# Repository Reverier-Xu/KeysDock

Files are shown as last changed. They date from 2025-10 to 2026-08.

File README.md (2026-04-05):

# Keys Dock

The hall-effect powered, high performance, feature riched keyboard!

> [!WARNING]
> **STILL IN EARLY DEVELOPMENT!**
>
> - [ ] PCB design
> - [ ] Suitkit design
> - [ ] Firmware
> - [ ] Software
> - [ ] Extended external controllers

## Keys layout

KeysDock uses main dock with 80-keys ANSI layout.

## Suitkit design

Designed use [FreeCAD](https://www.freecad.org/) for 3D modeling and [QCAD](https://www.qcad.org/) for nameplate drawn.

Fonts used in design:

- [Iosevka](https://typeof.net/Iosevka/): An elegant monospace coding font;
- [Hershey Fonts](https://en.wikipedia.org/wiki/Hershey_fonts): a collection of vector fonts originally designed to be rendered using vectors on early cathode ray tube displays.

## Hardware design

Designed use [KiCAD](https://www.kicad.org/), validated on [QUCS-s](https://ra3xdh.github.io/).

- MCU and BLE/WiFi: ESP32-C6
- ADC: TLA2518
- Hall-effect sensors: SC4823S6-TR
- Magnetic switch: Gateron Low Profile Magnetic Jade Pro Switch

More component info is available under [here](hardware/docs).

> [!WARNING]
> LIMITATIONS: the extended F-keys suite do not have sleep mode, awake functions and RGB lights.
> Hall-effect keyboard requires too many I/O pins, which makes difficulty in transfer additional features to external dock.

## Firmware

Rust 1.94 is required for build firmware.

## Software

WIP...

## Credits

This project is built entirely with opensource softwares, with power of opensource RISC-V instruction-set.

- [KiCAD](https://www.kicad.org): GPLv3
- [FreeCAD](https://www.freecad.org): LGPLv2.1
- [QCAD](https://www.qcad.org): GPLv3
- [Inkscape](https://www.inkscape.org): GPLv2
- [QUCS-s](https://ra3xdh.github.io): GPLv2
- [Rust](https://www.rust-lang.org): Apache-2.0 & MIT
- [esp-rs](https://docs.espressif.com/projects/rust/): Apache-2.0 & MIT

The current keyboard scheme can roughly be regarded as an original one.

Additionally, special thanks to [LCEDA](https://lceda.cn/), some 3D component models in this project are sourced from here.

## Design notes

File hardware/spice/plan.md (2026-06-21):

# KeysDock SPICE Simulation Plan

## Objective
Use ngspice to validate the KeysDock rev 0.3.0 hardware across power, analog, digital, and reliability domains.

## Model Sourcing Strategy
1. **First-party manufacturer models** — downloaded from TI where available and unencrypted.
2. **Third-party open-source libraries** — KiCad Spice Library, LTwiki, ngspice examples (checked; no direct matches for the exotic parts).
3. **Custom behavioral models** — built from datasheets when no compatible model exists.

## Model Inventory

| Component | MPN | Source | File | ngspice status | Usage |
|---|-----|---|---|---|---|
| Load switch | TPS22910AYZVR | TI first-party (SLVMA45A) | `models/vendor/ti/SLVMA45A/SLVMA45/TPS22910A_TRANS.LIB` | Reference only — uses PSpice digital primitives incompatible with ngspice 46 | Behavioral replacement used in sims |
| Buck converter | TPS62142RGTR | TI first-party (SLVM442B) | `models/vendor/ti/SLVM442B/TPS62142_PSPICE_TRANS/TPS62142_TRANS.lib` | Reference only — uses PSpice constructs incompatible with ngspice 46 | Behavioral replacement used in sims |
| ADC | TLA2528 (similar family) | TI first-party (SBAM431) | `models/vendor/ti/SBAM431/TLA2528_TRANS.LIB` | Reference only — TINA format, not ngspice compatible | Behavioral TLA2518 AFE used in sims |
| Charger / power-path | BQ24074RGTR | TI — **no SPICE model offered** | N/A | Custom behavioral | `models/custom/bq24074.lib` |
| Analog mux | XL4067TS | XINLUDA — no model | N/A | Custom behavioral | `models/custom/xl4067ts.lib` |
| Hall sensor | SC4823S6-TR | Semiment — no model | N/A | Custom behavioral | `models/custom/sc4823s6.lib` |
| RGB LED | XL-6028RGBW-WS2812B | XINGLIGHT — no model | N/A | Custom behavioral load | `models/custom/ws2812b.lib` |
| ESD array | TPD4E05U06DQAR | TI — no SPICE model | N/A | Generic TVS behavioral | `models/custom/tvs.lib` |
| ESD diode | TPD1E10B06DPYR | TI — no SPICE model | N/A | Generic TVS behavioral | `models/custom/tvs.lib` |
| TVS | TS24CA | SHOU HAN — no model | N/A | Generic TVS behavioral | `models/custom/tvs.lib` |
| Schottky | SM4007PL | MCC — generic model | N/A | Generic diode | ngspice built-in + `models/custom/diode.lib` |
| Inductor | 2.2µH | cjiang — no model | N/A | Ideal + DCR | `models/custom/passive.lib` |

## Simulation Matrix

| ID | Title | Circuit | Key Metrics | Priority |
|----|---|---|---|---|
| SP01 | VBAT monitor divider & ADC input range | `circuits/sp01_vbat_divider.cir` | AIN7 vs VBAT, overvoltage at VBAT=4.5V | P0 |
| SP02 | BQ24074 power-path & charger behavior | `circuits/sp02_charger.cir` | +4V vs VIN/VBAT, charge current, TS fault | P0 |
| SP03 | TPS62142 buck regulation & load transient | `circuits/sp03_buck.cir` | Vout regulation, ripple, inrush with 220µF | P0 |
| SP04 | Hall → mux → ADC signal chain | `circuits/sp04_hall_mux_adc.cir` | Settling time, scan time, noise | P0 |
| SP05 | Mux crosstalk | `circuits/sp05_mux_crosstalk.cir` | Coupling from active channel to quiet channel | P1 |
| SP06 | Ground noise / NetTie star ground | `circuits/sp06_ground_noise.cir` | GNDA bounce vs GNDD with LED switching | P1 |
| SP07 | PDN impedance | `circuits/sp07_pdn_impedance.cir` | |Z| of +3.3V vs frequency | P1 |
| SP08 | Hall sleep / wake timing | `circuits/sp08_sleep_wake.cir` | RANA latency, SAKI_MOVE pulse | P1 |
| SP09 | USB VBUS TVS clamp | `circuits/sp09_usb_vbus_tvs.cir` | Clamp voltage, peak current | P1 |
| SP10 | USB data-line ESD clamp | `circuits/sp10_usb_data_tvs.cir` | D+/D- clamp, loading capacitance | P1 |
| SP11 | ADC reference / sampling glitches | `circuits/sp11_adc_sampling.cir` | Acquisition error vs source impedance | P1 |
| SP12 | TPS22910A LED load-switch inrush & current budget | `circuits/sp12_led_load_switch.cir` | Inrush, VCC droop, max DC current | P1 |
| SP13 | VBAT ripple and Schottky behavior | `circuits/sp13_vbat_ripple.cir` | Schottky behavior, battery ripple | P2 |
| SP14 | ESP32 strapping / power-on (behavioral) | `circuits/sp14_strapping.cir` | Boot pin levels at power-up | P2 |
| SP15 | Buck inductor current ripple | `circuits/sp15_inductor_ripple.cir` | Inductor current, saturation margin | P2 |
| SP16 | BQ24074 TS bias compliance | `circuits/sp16_ts_bias.cir` | TS/VIN window vs bias network | P0/P1 |

## How to Run

```bash
cd /home/reverier/Code/Hardware/KeysDock/hardware/spice
python3 scripts/run_all.py
```

Results are written to `results/` as CSV/PNG-compatible raw files and summarized in `reports/simulation-summary.md`.

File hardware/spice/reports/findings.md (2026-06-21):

# KeysDock SPICE Simulation Findings

## SP01

- Variables: v(v-sweep), v(vin), v(aout), i(vbat)
- **Result:** At VBAT=4.50V, AIN7=2.250V (ratio=0.500, expected 0.500). OK for TLA2518 0-3.3V range.
- Data points: 16

## SP02

- Variables: time, v(vusb), v(vin), v(bat), v(xbat.n_int), v(xu4.vin_ok)...
- **Result:** USB present: SYS=4.38V, BAT=3.55V, CHG=0.00V (charging (CHG active-low)), PGOOD=0.00V. TS bias at 750.0mV is valid (valid window 0.30V-2.10V).
- Data points: 826

## SP03

- Variables: time, v(vin), v(vreg), v(vout), i(vbuck), i(vin)
- **Result:** Vout min=-0.000V, max=3.300V, final=3.295V (target 3.3V). ~220µF output capacitance causes prolonged soft-start but regulates.
- Data points: 70040

## SP04

- Variables: time, v(vdd), v(mag), v(sleep), v(xhall.sleep_int), v(xhall.gidd_int1)...
- **Result:** Hall output step tracked by mux/ADC. Final ADC code=1.650V vs hall=1.650V. Settling is within ~1µs for 200Ω Ron + 20pF load.
- Data points: 3044

## SP05

- Variables: time, v(vdd), v(s0), v(s1), v(eb), v(a0)...
- Data points: 508

## SP06

- Variables: time, v(gndd), v(gnda), v(ref), v(ain), i(lret)...
- Data points: 50027

## SP07

- Variables: frequency, v(vout), v(xc1.n3), v(xc2.n3), v(xc3.n3), v(xc4.n3)...
- Data points: 141

## SP08

- Variables: time, v(vdd), v(mag), v(sleep), v(xhall.sleep_int), v(xhall.gidd_int1)...
- Data points: 1529

## SP09

- Variables: time, v(vbus), v(esd), i(vesd)
- Data points: 524

## SP10

- Variables: time, v(src), v(dp), i(vesd)
- Data points: 426

## SP11

- Variables: time, v(vin), v(adc_in), v(xs1.samp_node), v(xs1.g1_int1), v(samp)...
- Data points: 3020

## SP12

- Variables: time, v(src), v(vin), v(xu6.en_int), v(on), v(xu6.vout_ctrl)...
- **Result:** Max input current=2.000A (limited by model), final VCC=2.081V. 82 RGBW LEDs at full white draw ~4.9A, exceeding TPS22910A 2A rating and USB 500mA limit. Firmware must enforce current budget.
- Data points: 50018

## SP13

- Variables: time, v(bat), v(sys), i(vbat)
- Data points: 508

## SP16

- Variables: v(v-sweep), v(vin), v(xu4.vin_ok), v(ts_good), v(xu4.gts_int1), v(xu4.ts_ok)...
- **Result:** At VIN=6.0V: 10kΩ TS-to-GND (datasheet NTC-disabled) V_TS=0.750V (OK, charging enabled); 22kΩ/47kΩ divider-to-VIN V_TS=5.21V (FAULT, exceeds VCOLD). Current schematic is correct per BQ24074 datasheet.
- Data points: 16

## Summary of Critical Findings

1. **BQ24074 TS bias is correct in current schematic.** R14=10kΩ from TS to GND matches the BQ24074 datasheet recommendation for NTC-disabled applications (TS voltage = ~0.75V, inside the 0.30V-2.10V valid window). The earlier ratio-based threshold model was wrong.
2. **LED current budget violation.** 82 WS2812B RGBW LEDs at full white draw ~4.9A, exceeding the TPS22910A 2A switch rating and the USB-C 500mA advertised limit. Firmware must limit brightness based on power source.
3. **+3.3V output capacitance is large (~220µF).** TPS62142 regulates but soft-start is prolonged; verify loop stability and inrush on hardware.
4. **VBAT divider is correct.** R8/R9=100kΩ gives AIN7 = VBAT/2, staying within TLA2518 0-3.3V range for VBAT up to 4.5V.

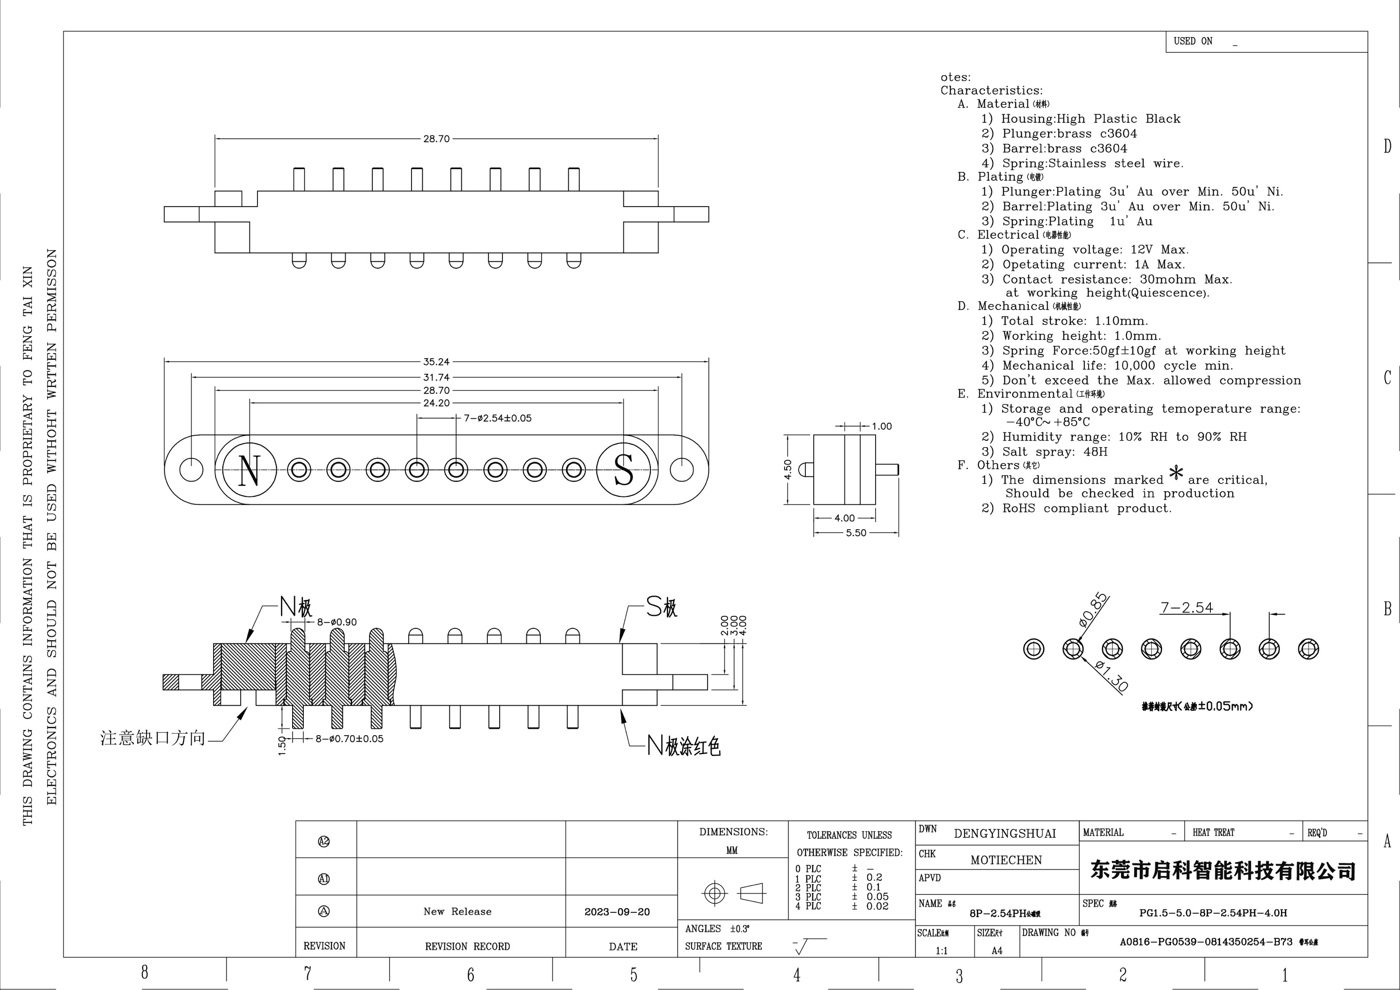
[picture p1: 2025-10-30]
hardware/docs/pogopin-ext.png

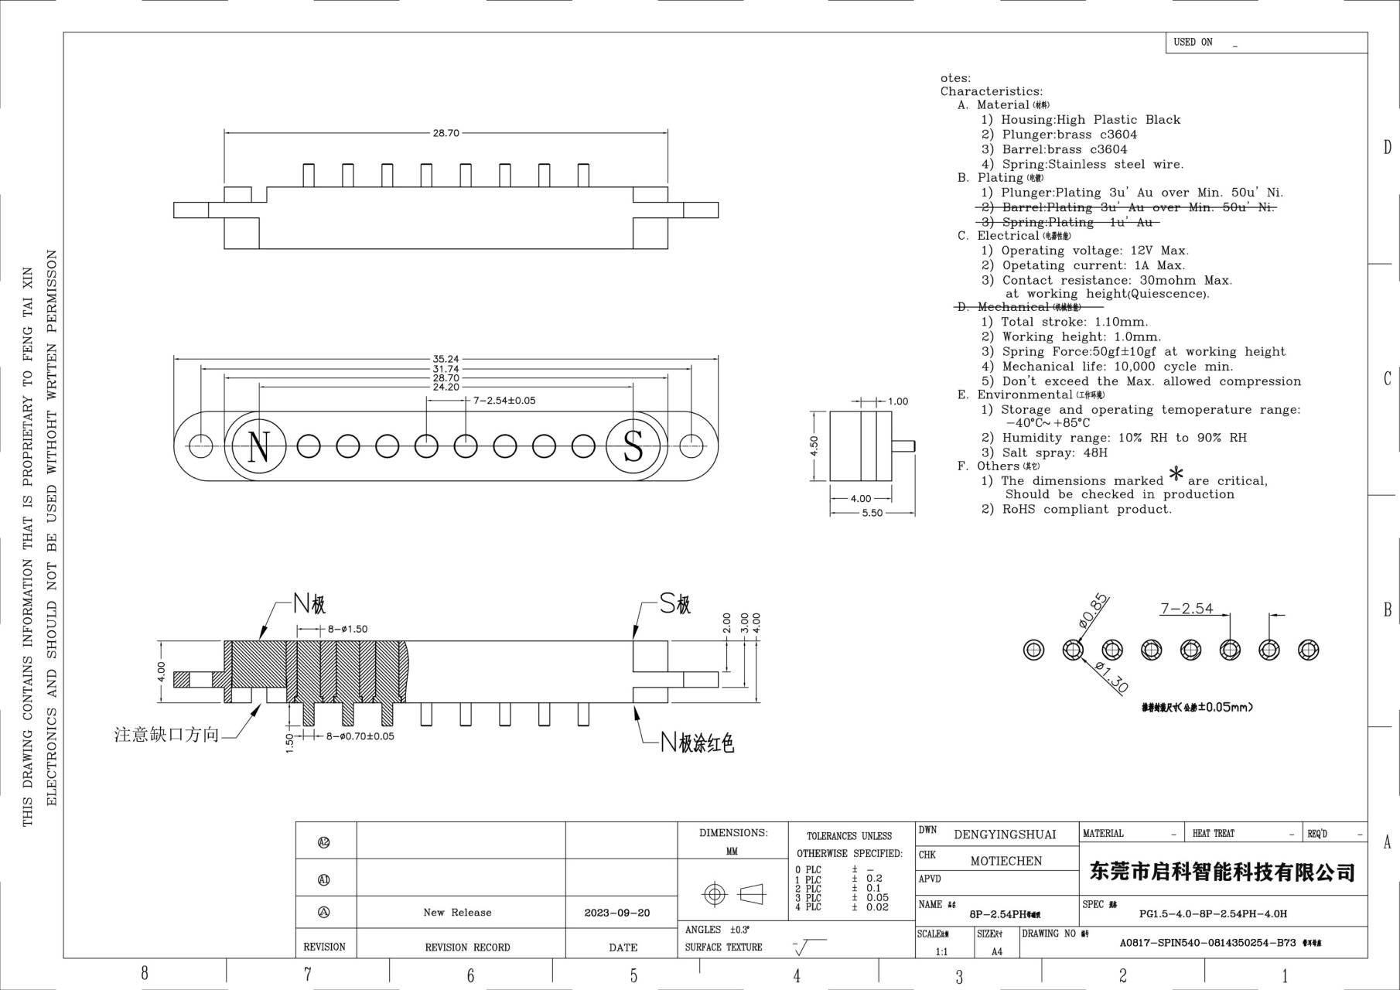
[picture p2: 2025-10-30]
hardware/docs/pogopin-main.png

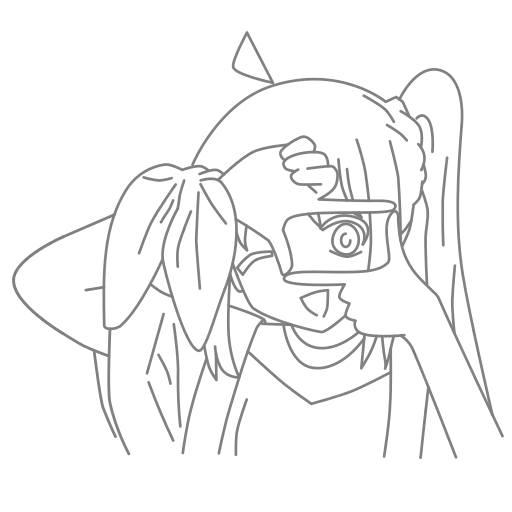
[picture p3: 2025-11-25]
arts/nijika.webp

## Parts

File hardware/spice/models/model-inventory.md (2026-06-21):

# SPICE Model Inventory

## First-party manufacturer models (reference)

| Part | Literature | Download URL | File location | Compatibility |
|---|---|---|---|---|
| TPS22910AYZVR | SLVMA45A | https://www.ti.com/lit/zip/SLVMA45A | `models/vendor/ti/SLVMA45A/` | PSpice; uses digital primitives that fail in ngspice 46 |
| TPS62142RGTR | SLVM442B | https://www.ti.com/lit/zip/SLVM442B | `models/vendor/ti/SLVM442B/` | PSpice unencrypted; uses constructs incompatible with ngspice 46 |
| TLA2528 (TLA2518 family) | SBAM431 | https://www.ti.com/lit/zip/SBAM431 | `models/vendor/ti/SBAM431/` | TINA format; not ngspice compatible |

## Third-party / open-source searches

- KiCad Spice Library (GitHub): no matches for XL4067TS, SC4823S6, BQ24074, TLA2518.
- LTwiki / ngspice examples: no specific models for these parts.
- Diodes Inc / ON Semi / Infineon libraries: not applicable to these TI/XINLUDA/Semiment parts.

## Custom behavioral models (used in simulations)

| Part | File | Basis |
|---|---|---|
| BQ24074RGTR | `models/custom/bq24074.lib` | Datasheet equations for charge current, input current limit, power-path, TS window |
| TPS62142RGTR | `models/custom/tps62142.lib` | Datasheet: fixed 3.3V, 2A current limit, soft-start, PG |
| TLA2518 AFE | `models/custom/tla2518_afe.lib` | Datasheet: 500Ω input switch, 12pF sample cap, 12-bit quantizer |
| TPS22910AYZVR | `models/custom/tps22910a.lib` | Datasheet: 60mΩ Ron, active-low, slew-limited turn-on, reverse-current protection |
| XL4067TS | `models/custom/xl4067ts.lib` | Datasheet: 200Ω Ron, 5pF channel cap, 20pF output cap |
| SC4823S6-TR | `models/custom/sc4823s6.lib` | Datasheet: 1.65V quiescent, 3.3mV/Gs, sleep/wake |
| WS2812B LED | `models/custom/ws2812b.lib` | Datasheet: 18-60mA per LED, 100nF decoupling |
| TVS diodes | `models/custom/diode.lib` | Datasheet clamp levels for TPD4E05U06, TPD1E10B06, TS24CA |
| Passives / traces | `models/custom/passive.lib` | Vendor typical ESL/ESR values for 0402/1206 caps and 2.2µH inductor |

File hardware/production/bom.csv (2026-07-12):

Designator | Footprint | Quantity | Value | LCSC Part #
C1, C12, C15, C2, C32, C4, C5 | C_0402 | 7 | 1uF | C52923
C10, C16, C19, C22, C25, C28, C31, C33, C34 | C_0402 | 9 | 10uF | C15525
C100, C101, C102, C103, C104, C105, C106, C107, C108, C109, C110, C111, C112, C113, C114, C115, C116, C117, C118, C17, C20, C23, C26, C29, C3, C37, C38, C39, C40, C41, C42, C43, C44, C45, C46, C47, C48, C49, C50, C51, C52, C53, C54, C55, C56, C57, C58, C59, C60, C61, C62, C63, C64, C65, C66, C67, C68, C69, C7, C70, C71, C72, C73, C74, C75, C76, C77, C78, C79, C8, C80, C81, C82, C83, C84, C85, C86, C87, C88, C89, C9, C90, C91, C92, C93, C94, C95, C96, C97, C98, C99 | C_0402 | 91 | 100nF | C1525
C11 | C_0402 | 1 | 3.3nF | C26404
C13, C14, C18, C21, C24, C27, C30 | C_0402 | 7 | 4.7uF | C23733
C35, C36 | C_1206 | 2 | 100uF | C15008
C6 | C_0402 | 1 | 22uF | C105226
D1 | D_SOD-123FL | 1 | SM4007PL | C78741
D2 | DIO_TPD1E05U06DPYR | 1 | TPD1E10B06DPYR | C48260
J1 | USB-C-SMD_SHOUHAN_TYPE-C-16PFS-2JCB1.2-H6.5 | 1 | TYPE-C 16PFS 2JCB1.2-H6.5 IPX8 | C3020046
L1 | IND-SMD_L2.5-W2.0_MHCHL2520 | 1 | 2.2uH | C5832372
LED1, LED10, LED11, LED12, LED13, LED14, LED15, LED16, LED17, LED18, LED19, LED2, LED20, LED21, LED22, LED23, LED24, LED25, LED26, LED27, LED28, LED29, LED3, LED30, LED31, LED32, LED33, LED34, LED35, LED36, LED37, LED38, LED39, LED4, LED40, LED41, LED42, LED43, LED44, LED45, LED46, LED47, LED48, LED49, LED5, LED50, LED51, LED52, LED53, LED54, LED55, LED56, LED57, LED58, LED59, LED6, LED60, LED61, LED62, LED63, LED64, LED65, LED66, LED67, LED68, LED69, LED7, LED70, LED71, LED72, LED73, LED74, LED75, LED76, LED77, LED78, LED79, LED8, LED80, LED81, LED82, LED9 | XL-6028RGBW-WS2812B | 82 | XL-6028RGBW-WS2812B | C42163197
PC1 | HC-1.25-4PWT | 1 | HC-1.25-4PWT | C2845381
PC2 | HC-1.25-2PWT | 1 | HC-1.25-2PWT | C2845379
R1, R11, R14, R2, R23, R3, R4 | R_0402 | 7 | 10kΩ | C25744
R10, R8, R9 | R_0402 | 3 | 100kΩ | C25741
R12, R13 | R_0402 | 2 | 1.5kΩ | C25867
R15 | R_0402 | 1 | 1.10kΩ | C25860
R16 | R_0402 | 1 | 47kΩ | C25792
R17 | R_0402 | 1 | 3kΩ | C25784
R18 | R_0402 | 1 | 750Ω | C25132
R19, R20 | R_0402 | 2 | 22Ω | C25092
R21, R22 | R_0402 | 2 | 5.1kΩ | C25941
R5, R6 | R_0402 | 2 | 100Ω | C25076
R7 | R_0402 | 1 | 499Ω | C4125
S1 | TS24CA | 1 | TS24CA | C393942
S2 | SW_TS-1088-AR02016 | 1 | TS-1088-AR02016, 160gf | C720477
S3 | SW-SMD_SSSS811101 | 1 | SSSS811101 | C109335
SW1, SW10, SW11, SW12, SW13, SW14, SW15, SW16, SW17, SW18, SW19, SW2, SW20, SW21, SW22, SW23, SW24, SW25, SW26, SW27, SW28, SW29, SW3, SW30, SW31, SW32, SW33, SW34, SW35, SW36, SW37, SW38, SW39, SW4, SW40, SW41, SW42, SW43, SW44, SW45, SW46, SW47, SW48, SW49, SW5, SW50, SW51, SW52, SW53, SW54, SW55, SW56, SW57, SW58, SW59, SW6, SW60, SW61, SW62, SW63, SW64, SW65, SW66, SW67, SW68, SW69, SW7, SW70, SW71, SW72, SW73, SW74, SW75, SW76, SW77, SW78, SW8, SW9 | KD-SINGLE-KEY | 78 | SC4823S6-TR | C52021064
T1, T2, T3, T4, T5 | XL4067TS | 5 | XL4067TS | C41427445
U1 | ESP32-C6-WROOM-1 | 1 | ESP32-C6-WROOM-1-N8
U2 | QFN50P300X300X80-17N | 1 | TLA2518IRTER | C1855741
U3 | QFN50P300X300X80-17N | 1 | TPS62142RGTR | C129331
U4 | QFN50P300X300X80-17N | 1 | BQ24074RGTR | C54313
U5 | IC_TPD4E05U06DQAR | 1 | TPD4E05U06DQAR | C138714
U6 | BGA4N50P2X2_88X88X50N | 1 | TPS22910AYZVR | C205966

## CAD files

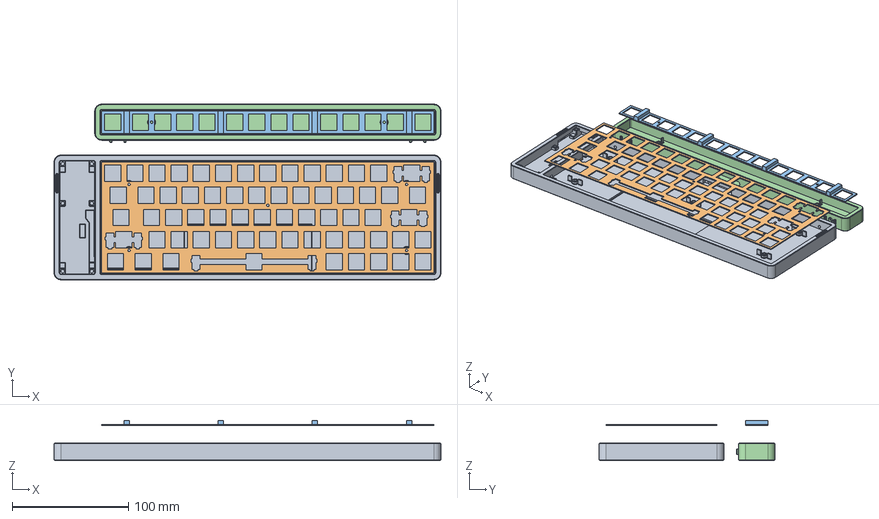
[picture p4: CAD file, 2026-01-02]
suitekits/full.FCStd
332.8 x 151.1 x 34.5 mm
Enclosure
Plate
FPlate
FEnclosure

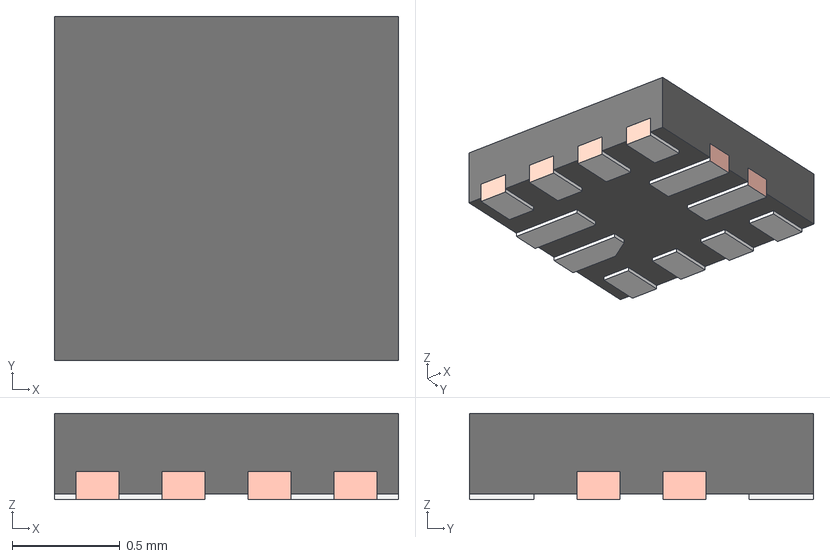
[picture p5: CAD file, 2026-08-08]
hardware/models/TUSB320LAIRWBR.step
1.60 x 1.60 x 0.4 mm
FRAME-RWB0012A
BODY-QFN

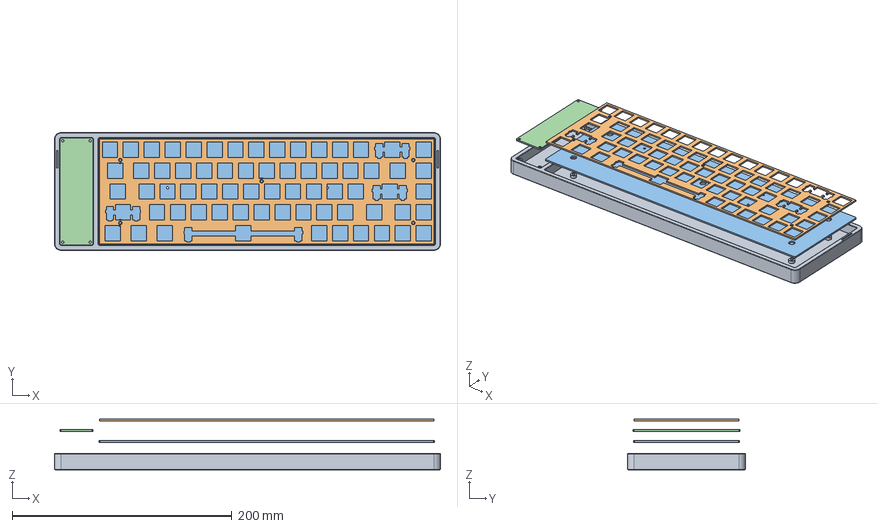
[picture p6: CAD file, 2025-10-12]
KeysDock65/suitekits/design.FCStd
351.5 x 107.2 x 46.1 mm
Enclosure
Plate
Stablizer
SideCover

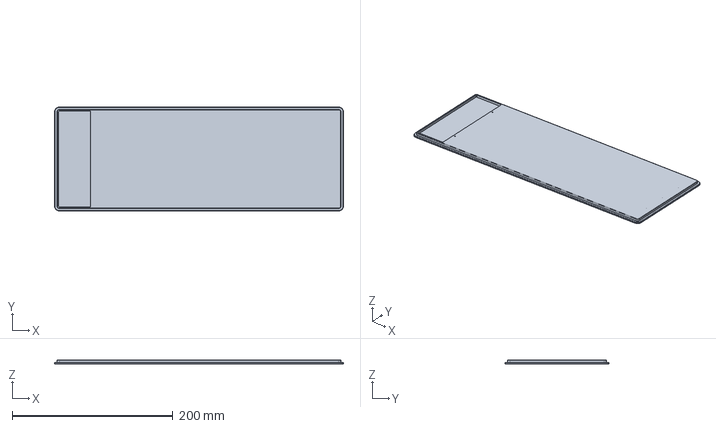
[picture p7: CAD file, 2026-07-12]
suitekits/KeysDock-Base.stp
359.8 x 129.3 x 5.00 mm

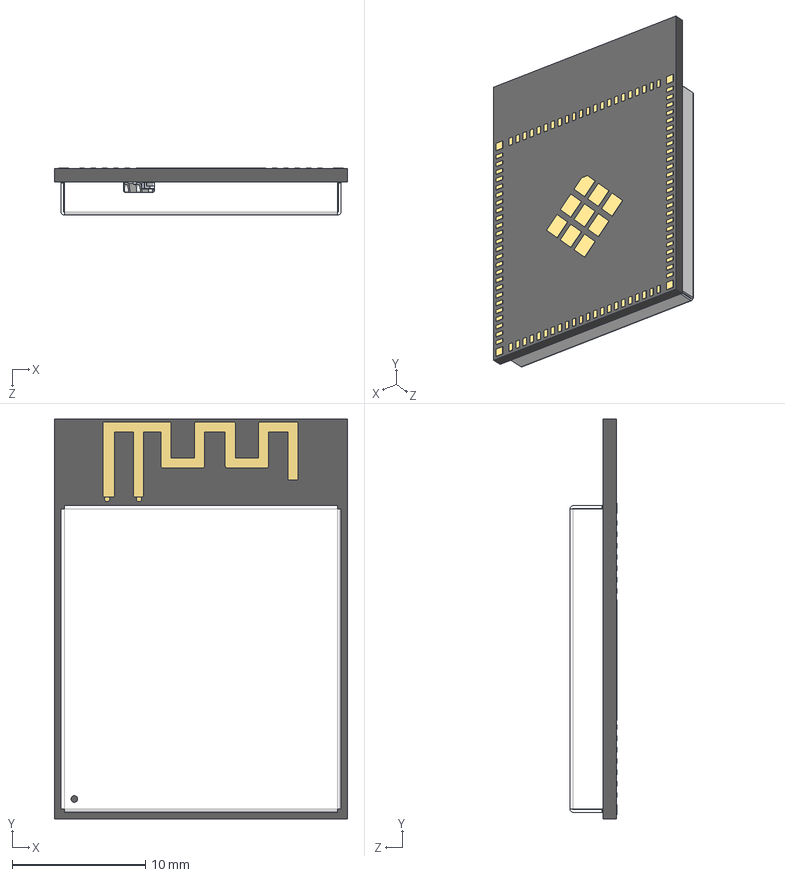
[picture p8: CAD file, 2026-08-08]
hardware/models/ESP32-S31-WROOM-3.step
22.0 x 30.0 x 3.54 mm
uid__4030
L0201_20210301.xtd x 5
C0201_20210301.xtd x 21
ESP32-S31 - 20260402.xtd
R0201_20210301.xtd x 11
SOD882.xtd
C0402_20210301.xtd x 3
SOP8_rev1_20210308.xtd
XTAL3225_20210301.xtd
Imported
MINI-ANT-TYPE-B
S31-wroom-3-solder_pad
ShieldBox_ESP32-S31-WROOM-3_V1.1_20260514

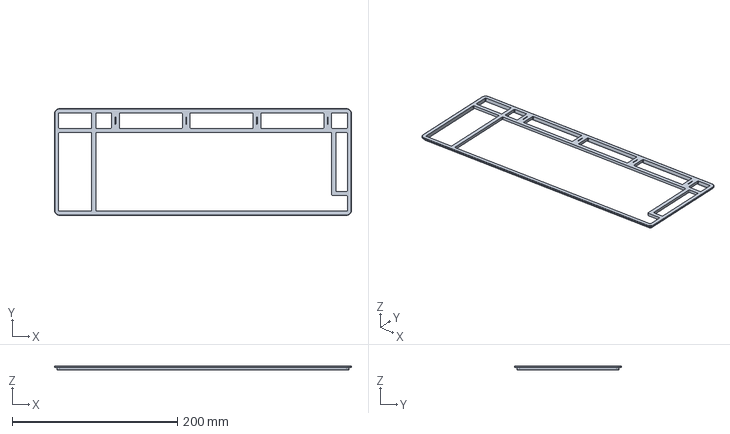
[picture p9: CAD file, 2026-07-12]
suitekits/KeysDock-Cover.stp
359.8 x 129.3 x 5.00 mm

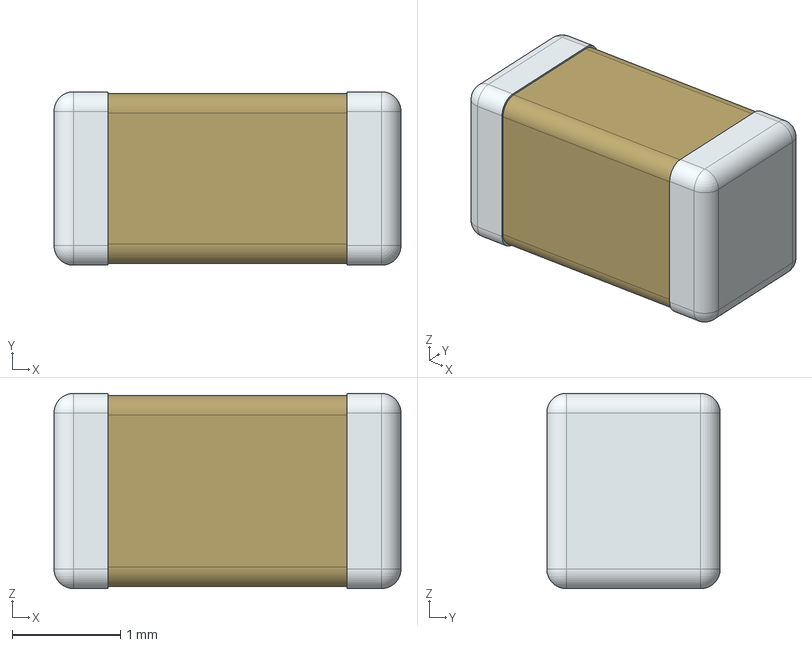
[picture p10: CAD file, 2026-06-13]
hardware/models/C_1206.step
3.20 x 1.60 x 1.80 mm

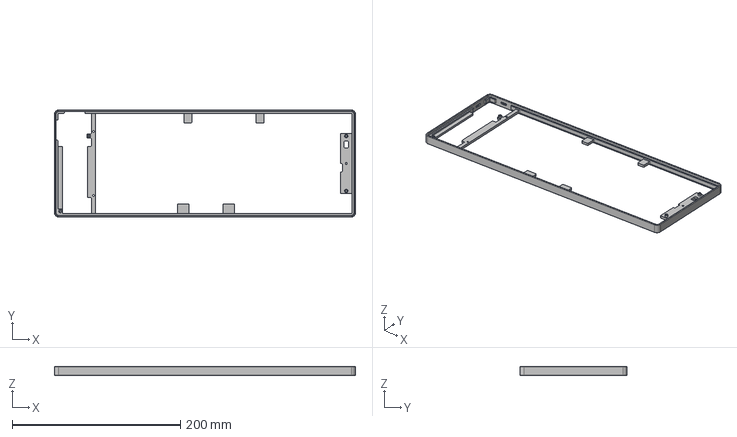
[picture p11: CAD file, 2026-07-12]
suitekits/KeysDock-Center.stp
357.8 x 127.3 x 11.0 mm

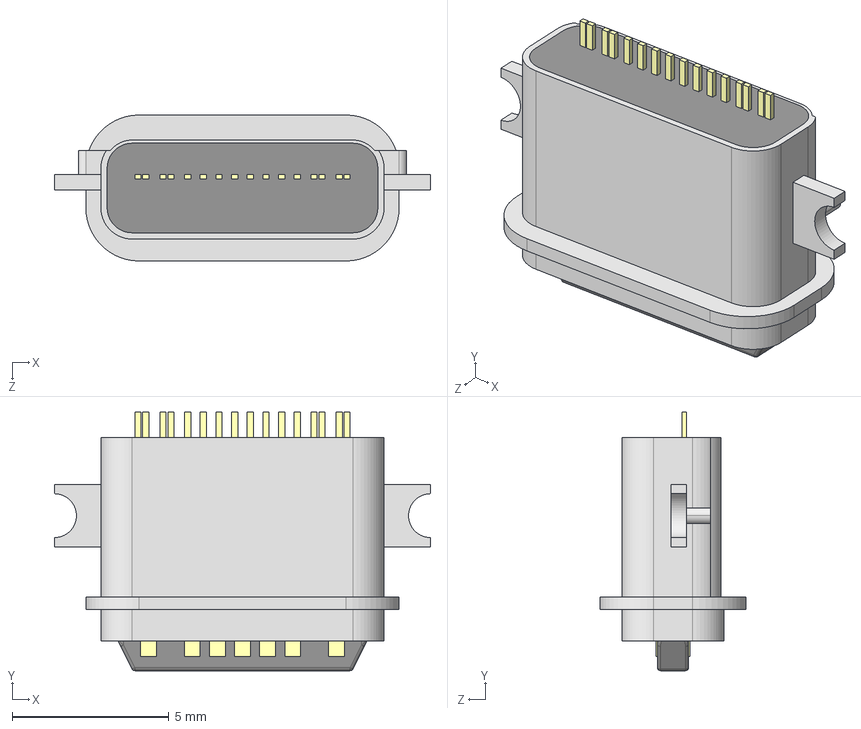
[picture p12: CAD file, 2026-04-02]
hardware/models/USB-C-SMD_SHOUHAN_TYPE-C-16PFS-2JCB1.2-H6.5.step
12.0 x 8.25 x 4.66 mm

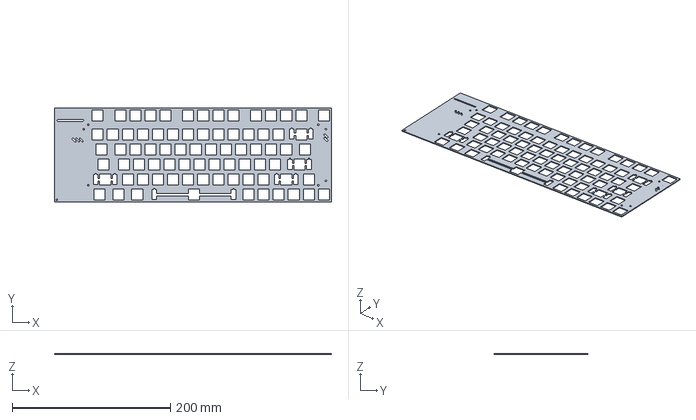
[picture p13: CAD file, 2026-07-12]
suitekits/KeysDock-Plate.stp
349.8 x 119.3 x 1.00 mm

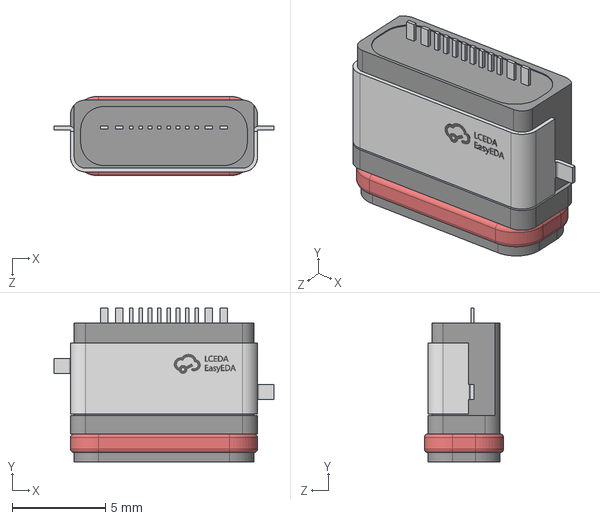
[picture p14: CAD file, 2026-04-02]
hardware/models/USB-C-SMD_SHOUHAN_TYPE-C-16PFS-2JCB1.2-H7.45.step
11.8 x 8.25 x 4.26 mm

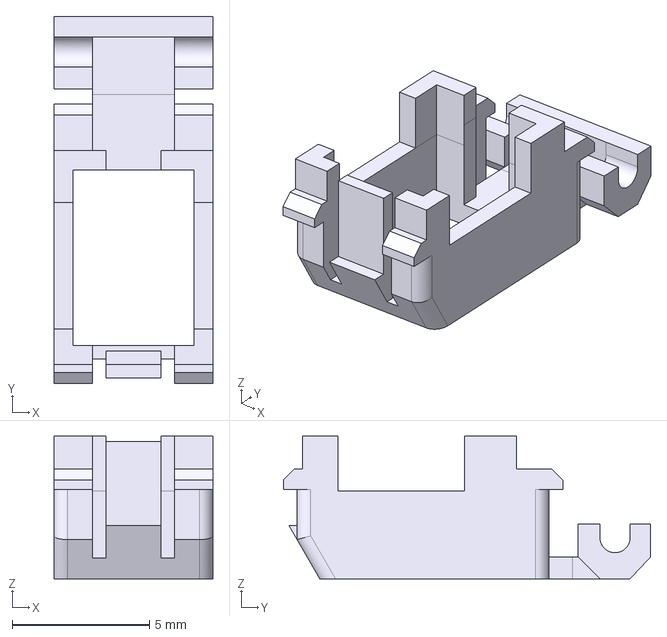
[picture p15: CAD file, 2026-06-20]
suitekits/KeysDock-Stabilizer-Mount.step
5.80 x 13.4 x 5.20 mm

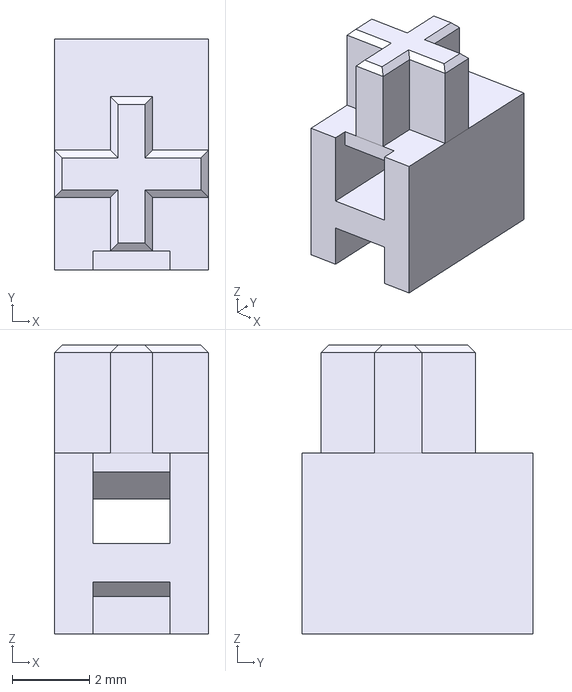
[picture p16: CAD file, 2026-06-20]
suitekits/KeysDock-Stabilizer-Route.step
4.00 x 6.00 x 7.50 mm

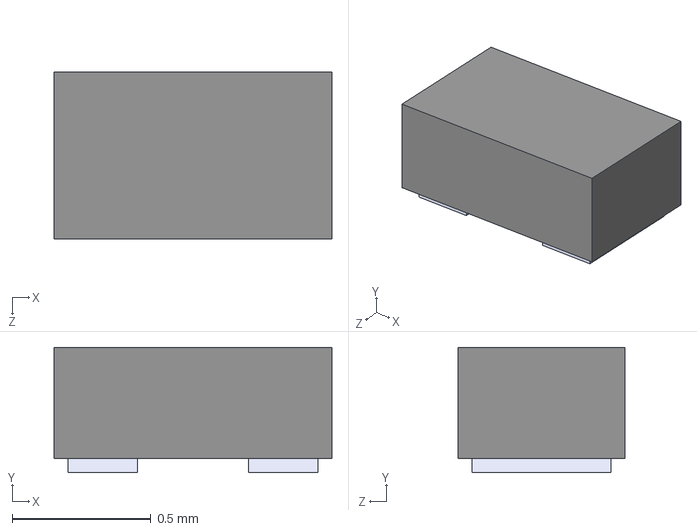
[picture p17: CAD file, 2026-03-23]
hardware/models/TPD1E10B06DPYR.step
1.00 x 0.45 x 0.6 mm

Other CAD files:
suitekits/KeysDock.FCStd
hardware/models/TPD4E05U06DQAR.step
hardware/models/LED-SMD_XL-3512RGBW.step
hardware/models/HC-TYPE-C-16P-CB1.6.step
hardware/models/AXK5F16347YG.step
hardware/models/AXK5F20347YG.step
hardware/models/AXK6F16347YG.step
hardware/models/AXK6F20347YG.step
hardware/models/BM28-16DP.stp
hardware/models/BM28-16DS.stp
hardware/models/CH334P.step
hardware/models/CH343P.step
hardware/models/C_0402.step
hardware/models/C_0603.step
hardware/models/Crystal_SMD-3225-4P.step
hardware/models/D_SOD-123FL.step
hardware/models/EC12E1240301.step
hardware/models/FPC-SMD_AFA01-S08FCA-00.step
hardware/models/FPC-SMD_AFC01-S12FCA-00.step
hardware/models/FPC-SMD_P0.50-16P_FGS-XJ-H2.0.step
hardware/models/HC-1.25-2PWT.step
hardware/models/HC-1.25-4PWT.step
hardware/models/IND-SMD_L2.5-W2.0_MHCHL2520.step
hardware/models/KS-33D-FB.step
hardware/models/LED-SMD_4P_XL-6028RGBW-WS2812B.step
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

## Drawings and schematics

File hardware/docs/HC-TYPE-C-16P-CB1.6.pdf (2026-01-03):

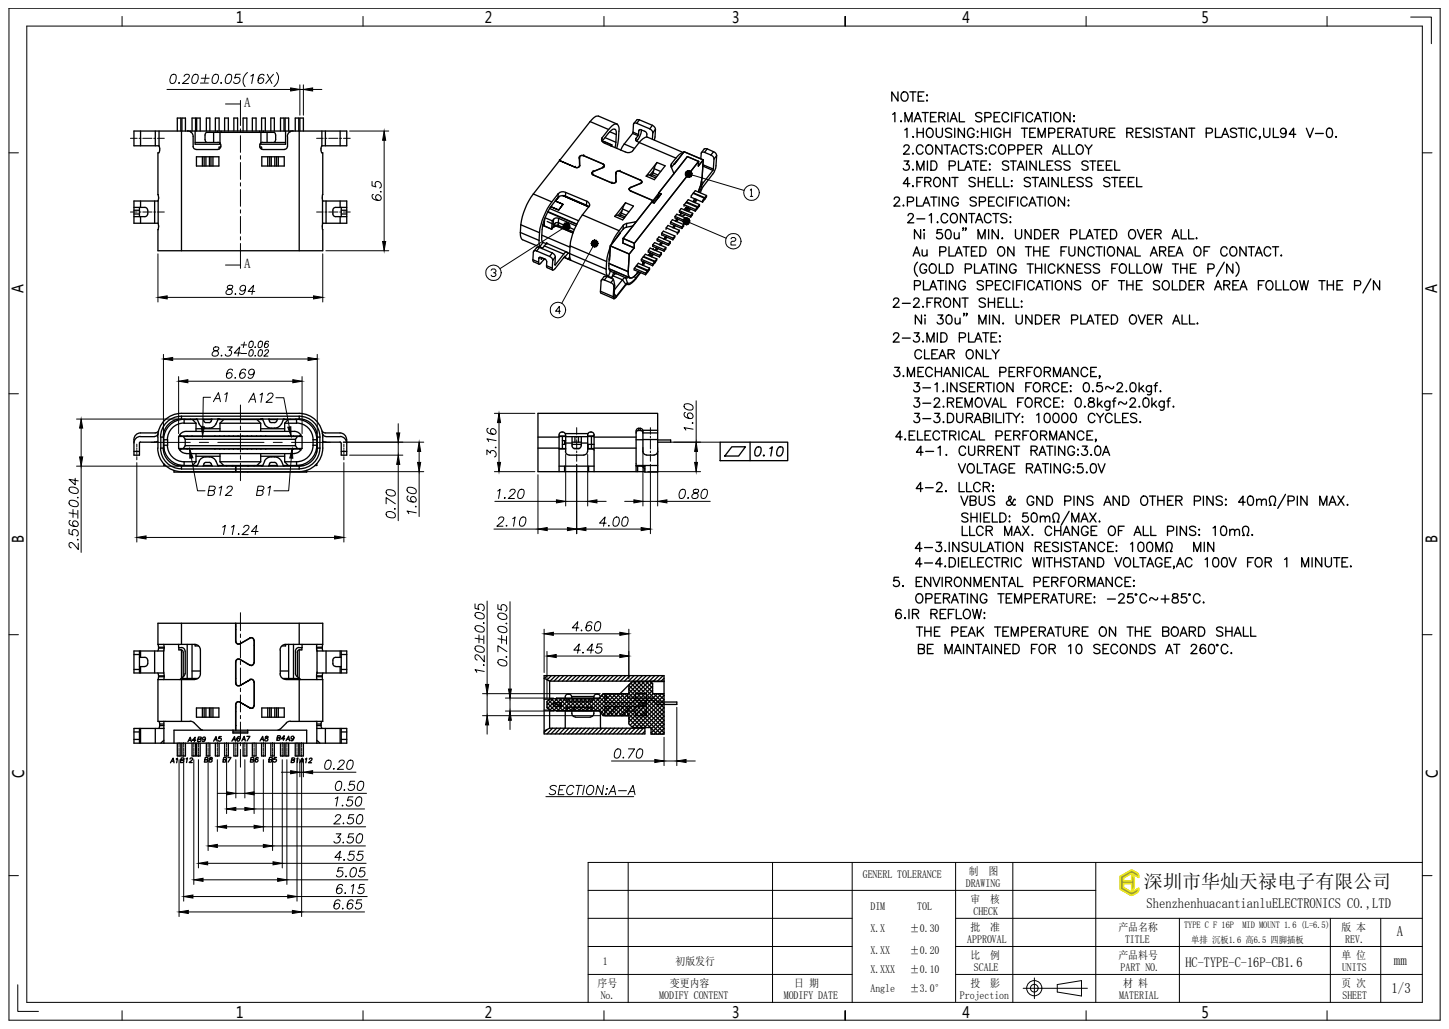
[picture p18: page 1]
HC-TYPE-C-16P-CB1.6 MATERIAL 材 料 PART NO. 产品料号 TITLE 产品名称 DRAWING 制 图 CHECK 审 核 APPROVAL 批 准 SCALE 比 例 Projection 投 影 GENERL TOLERANCE MODIFY DATE 日 期 MODIFY CONTENT 变更内容 1; 初版发行 No. 序号; REV. 版 本 UNITS 单 位 SHEET 页 次; mm 1/3 DIM; TOL X.X; ±0.20 X.XXX; ±0.10 Angle; 深圳市华灿天禄电子有限公司 ShenzhenhuacantianluELECTRONICS CO.,LTD A 1; B TYPE C F 16P MID MOUNT 1.6 (L=6.5) 单排 沉板1.6 高6.5 四脚插板 AA

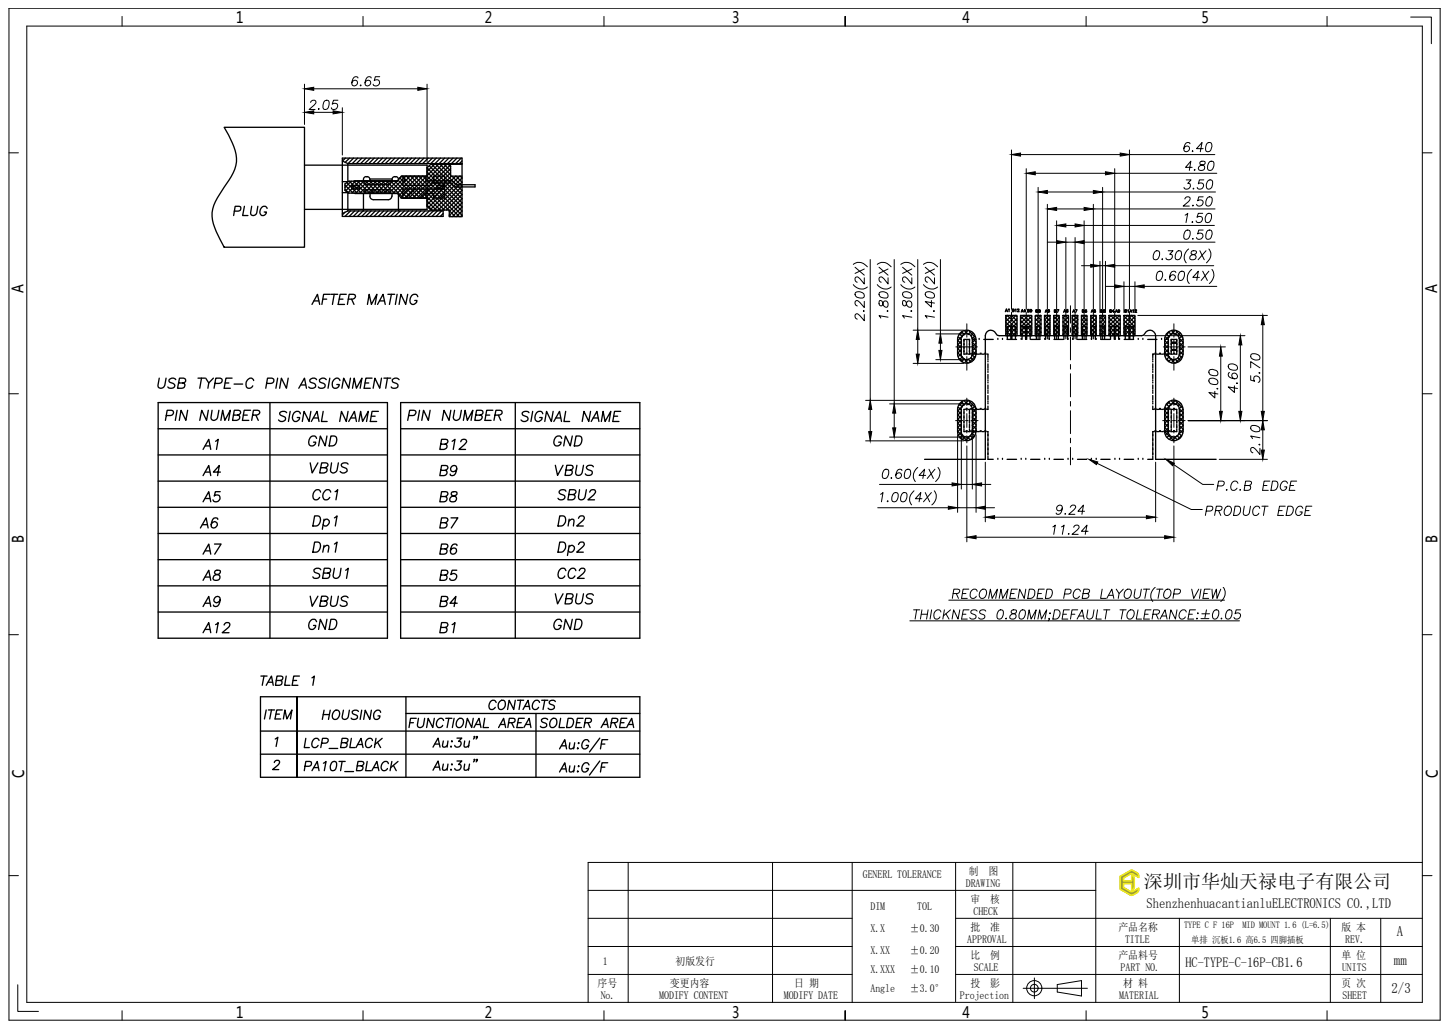
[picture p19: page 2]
HC-TYPE-C-16P-CB1.6 MATERIAL 材 料 PART NO. 产品料号 TITLE 产品名称 DRAWING 制 图 CHECK 审 核 APPROVAL 批 准 SCALE 比 例 Projection 投 影 GENERL TOLERANCE MODIFY DATE 日 期 MODIFY CONTENT 变更内容 1; 初版发行 No. 序号; REV. 版 本 UNITS 单 位 SHEET 页 次; mm 2/3 DIM; TOL X.X; ±0.20 X.XXX; ±0.10 Angle; 深圳市华灿天禄电子有限公司 ShenzhenhuacantianluELECTRONICS CO.,LTD A 1; B TYPE C F 16P MID MOUNT 1.6 (L=6.5) 单排 沉板1.6 高6.5 四脚插板

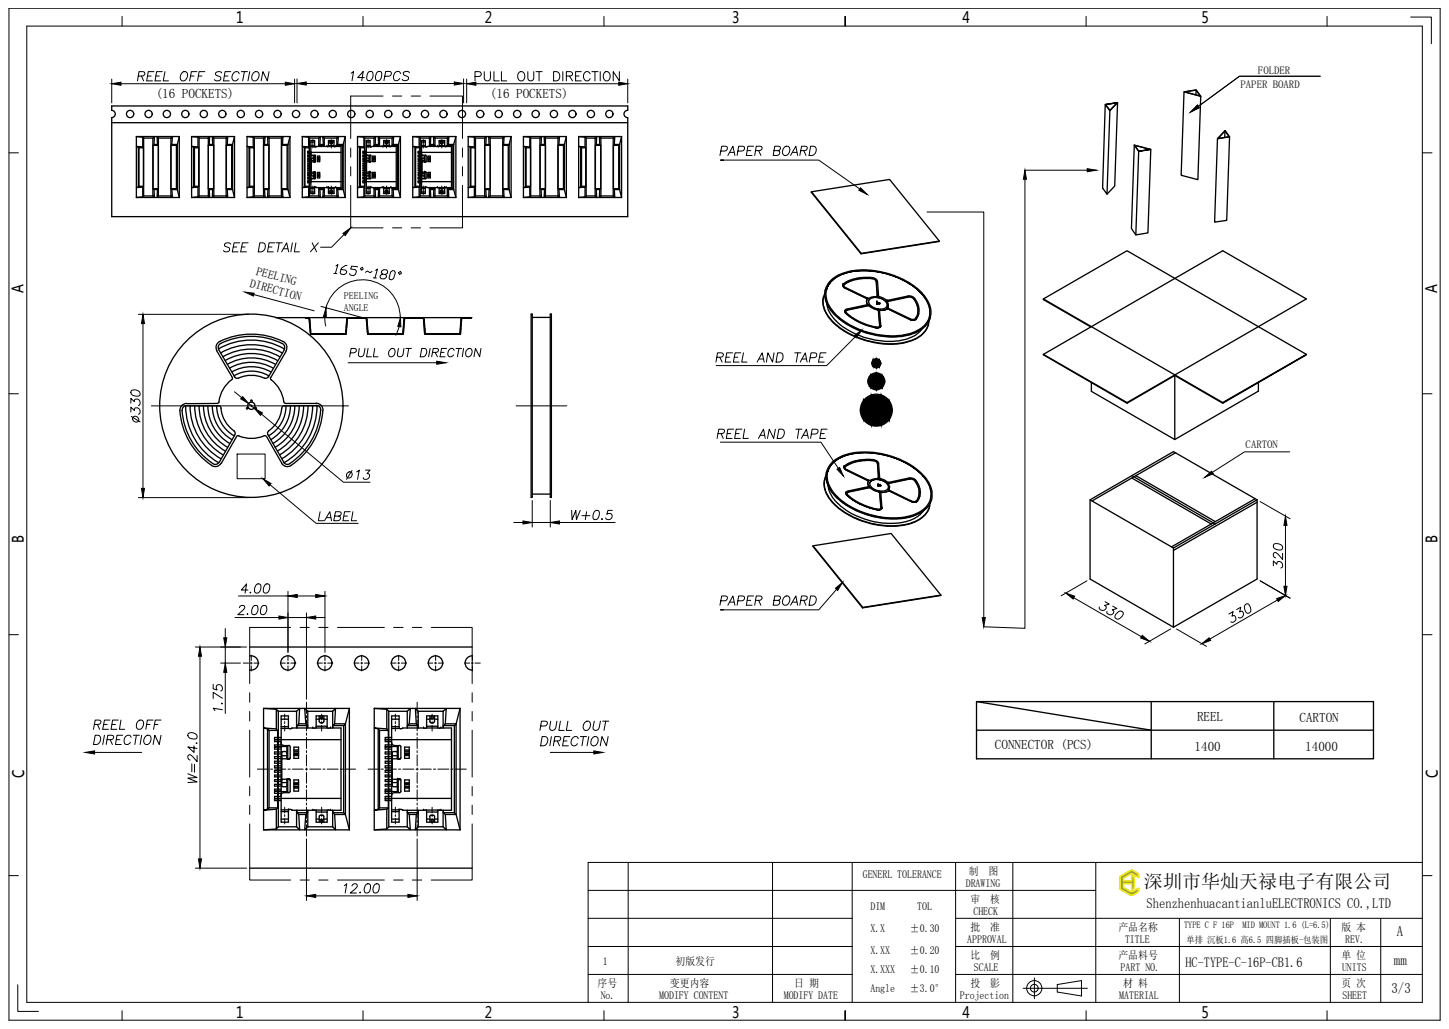
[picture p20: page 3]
HC-TYPE-C-16P-CB1.6 MATERIAL 材 料 PART NO. 产品料号 TITLE 产品名称 DRAWING 制 图 CHECK 审 核 APPROVAL 批 准 SCALE 比 例 Projection 投 影 GENERL TOLERANCE MODIFY DATE 日 期 MODIFY CONTENT 变更内容 1; 初版发行 No. 序号; REV. 版 本 UNITS 单 位 SHEET 页 次; mm 3/3 DIM; TOL X.X; ±0.20 X.XXX; ±0.10 Angle; 深圳市华灿天禄电子有限公司 ShenzhenhuacantianluELECTRONICS CO.,LTD A 1; B TYPE C F 16P MID MOUNT 1.6 (L=6.5) 单排 沉板1.6 高6.5 四脚插板-包装图 PEELING DIRECTION (16 POCKETS); (16 POCKETS) PEELING ANGLE; CONNECTOR (PCS); 14000 REEL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

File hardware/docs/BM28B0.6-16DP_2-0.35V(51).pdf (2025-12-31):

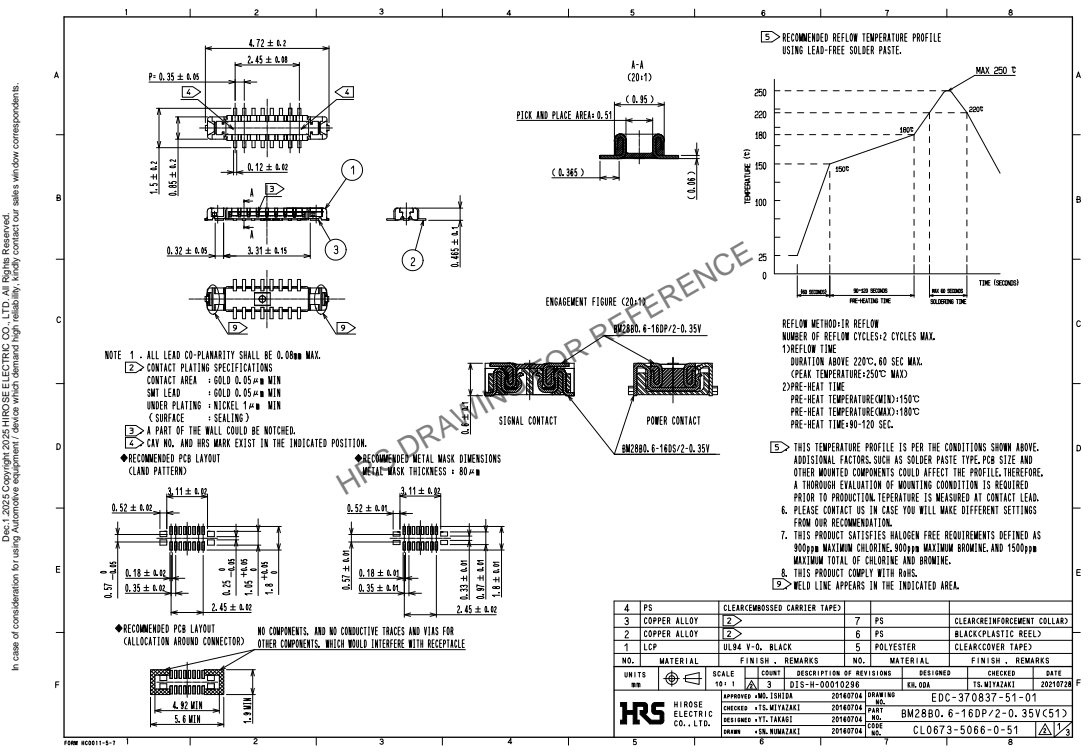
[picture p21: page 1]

HRS DRAWING FOR REFERENCE

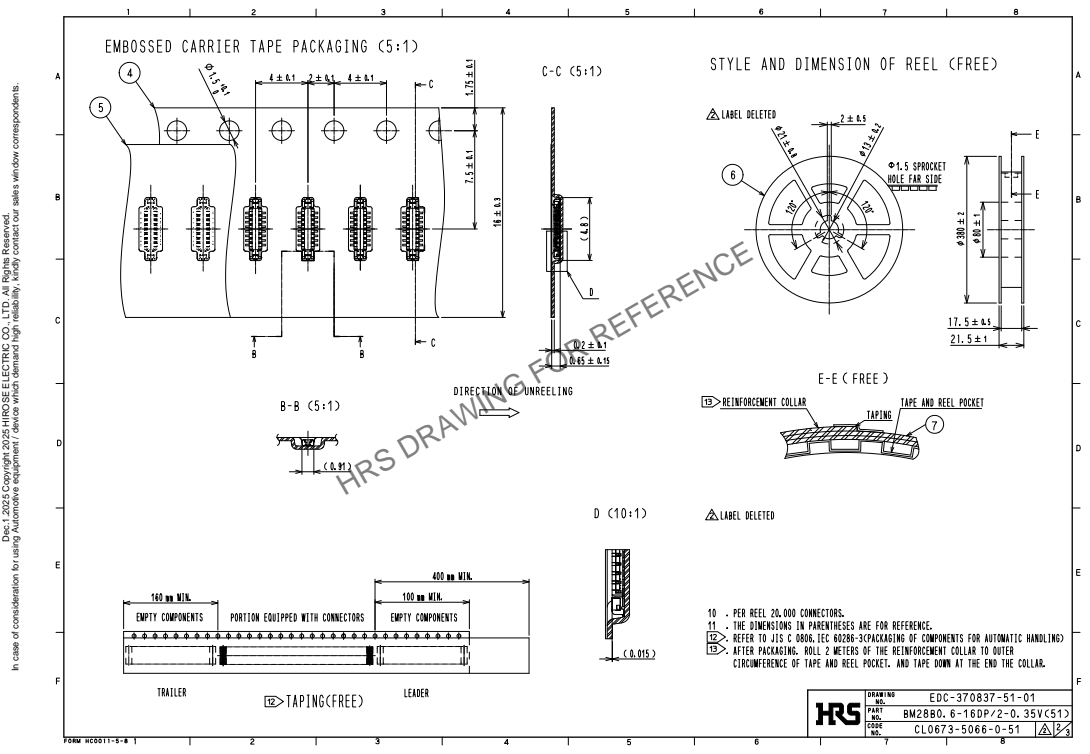
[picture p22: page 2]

HRS DRAWING FOR REFERENCE

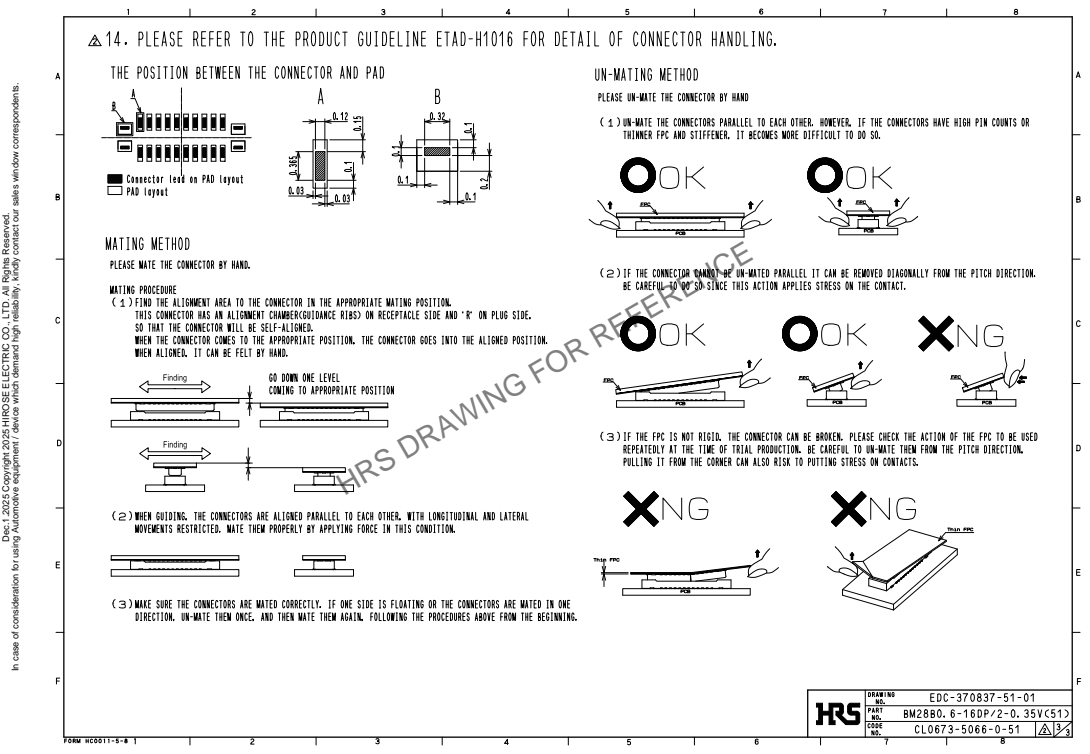
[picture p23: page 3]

HRS DRAWING FOR REFERENCE

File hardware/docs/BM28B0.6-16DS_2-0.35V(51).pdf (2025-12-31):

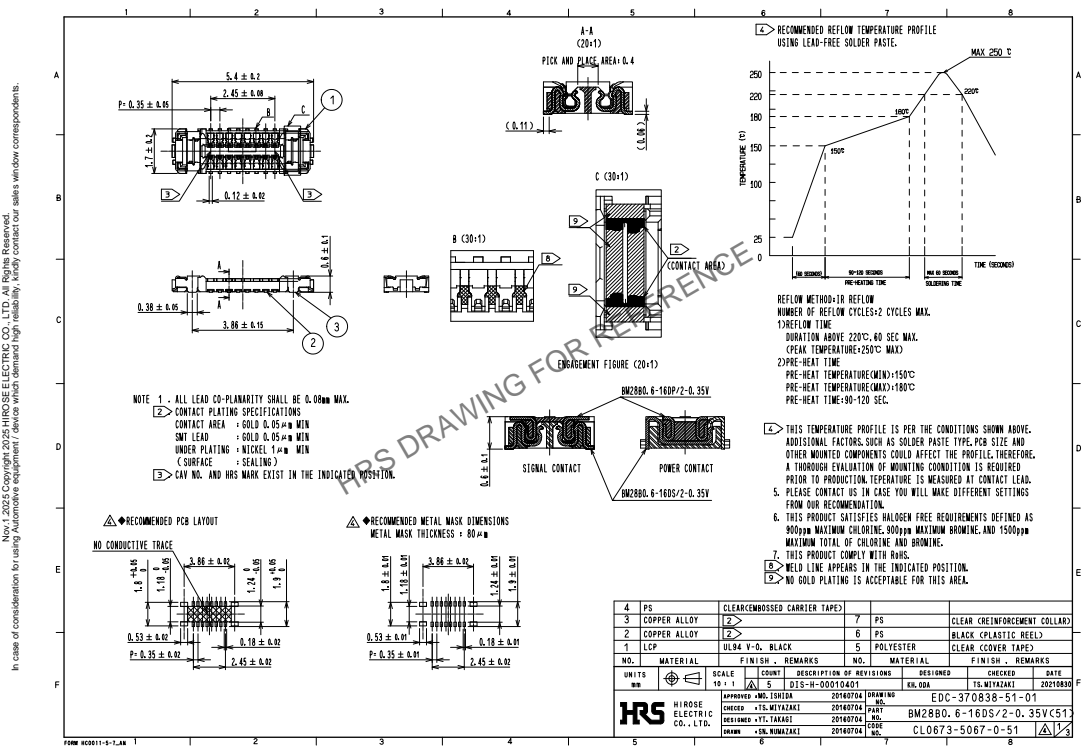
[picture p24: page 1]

HRS DRAWING FOR REFERENCE

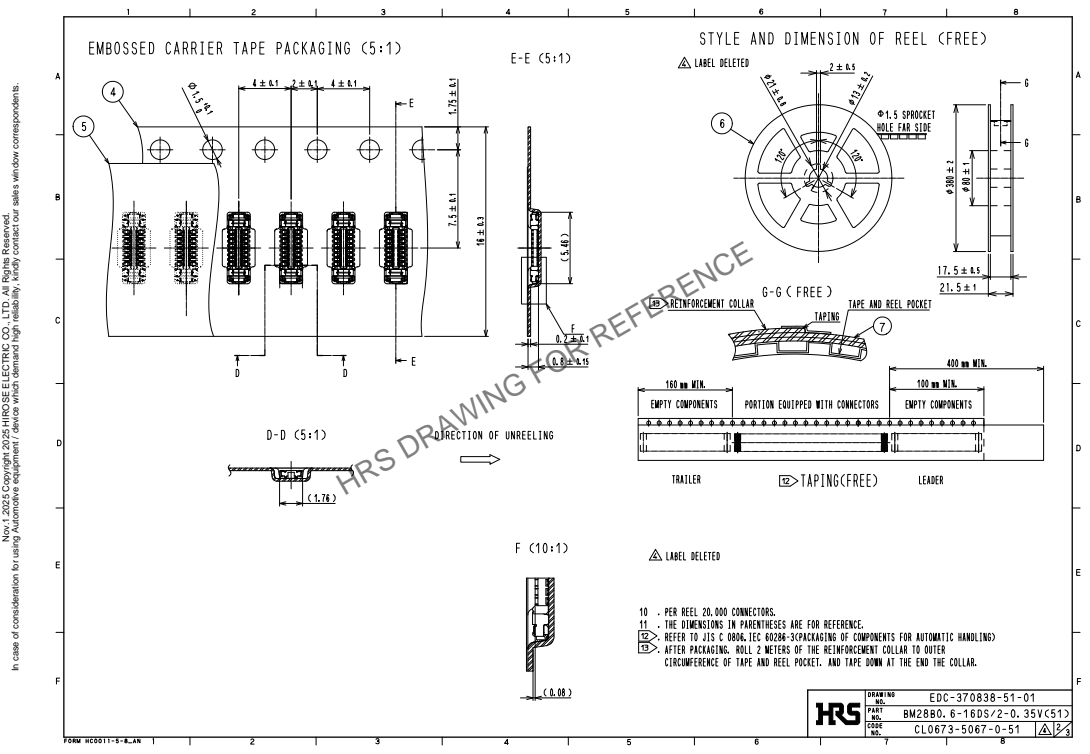
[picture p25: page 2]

HRS DRAWING FOR REFERENCE

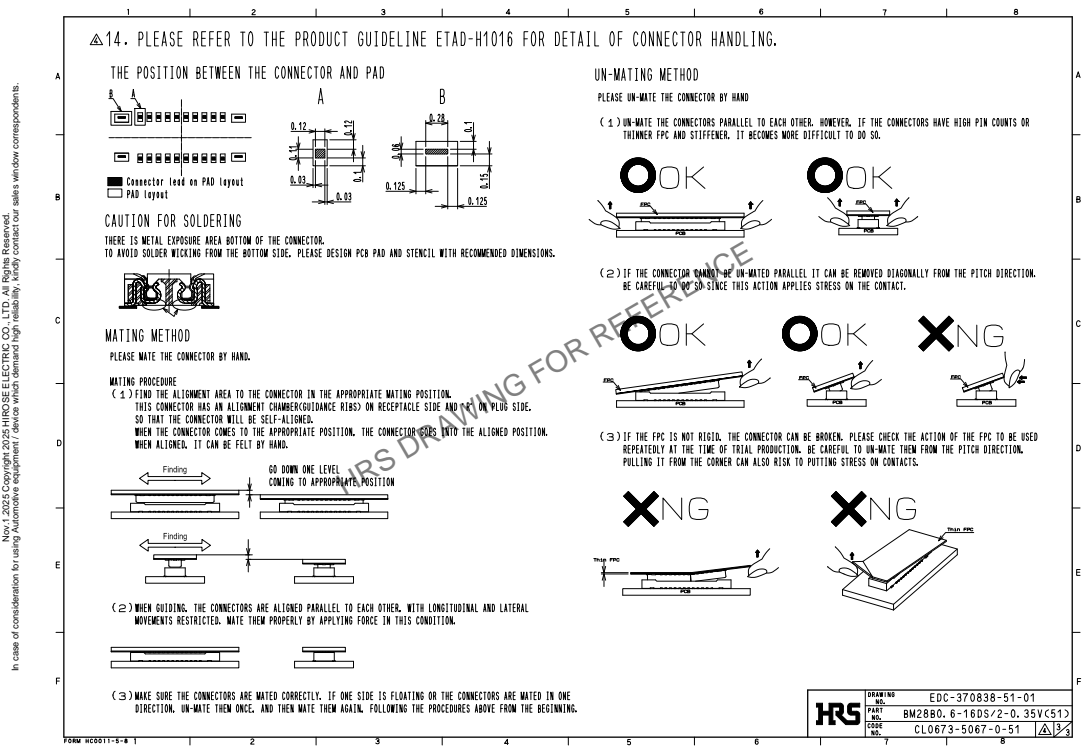
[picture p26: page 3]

HRS DRAWING FOR REFERENCE

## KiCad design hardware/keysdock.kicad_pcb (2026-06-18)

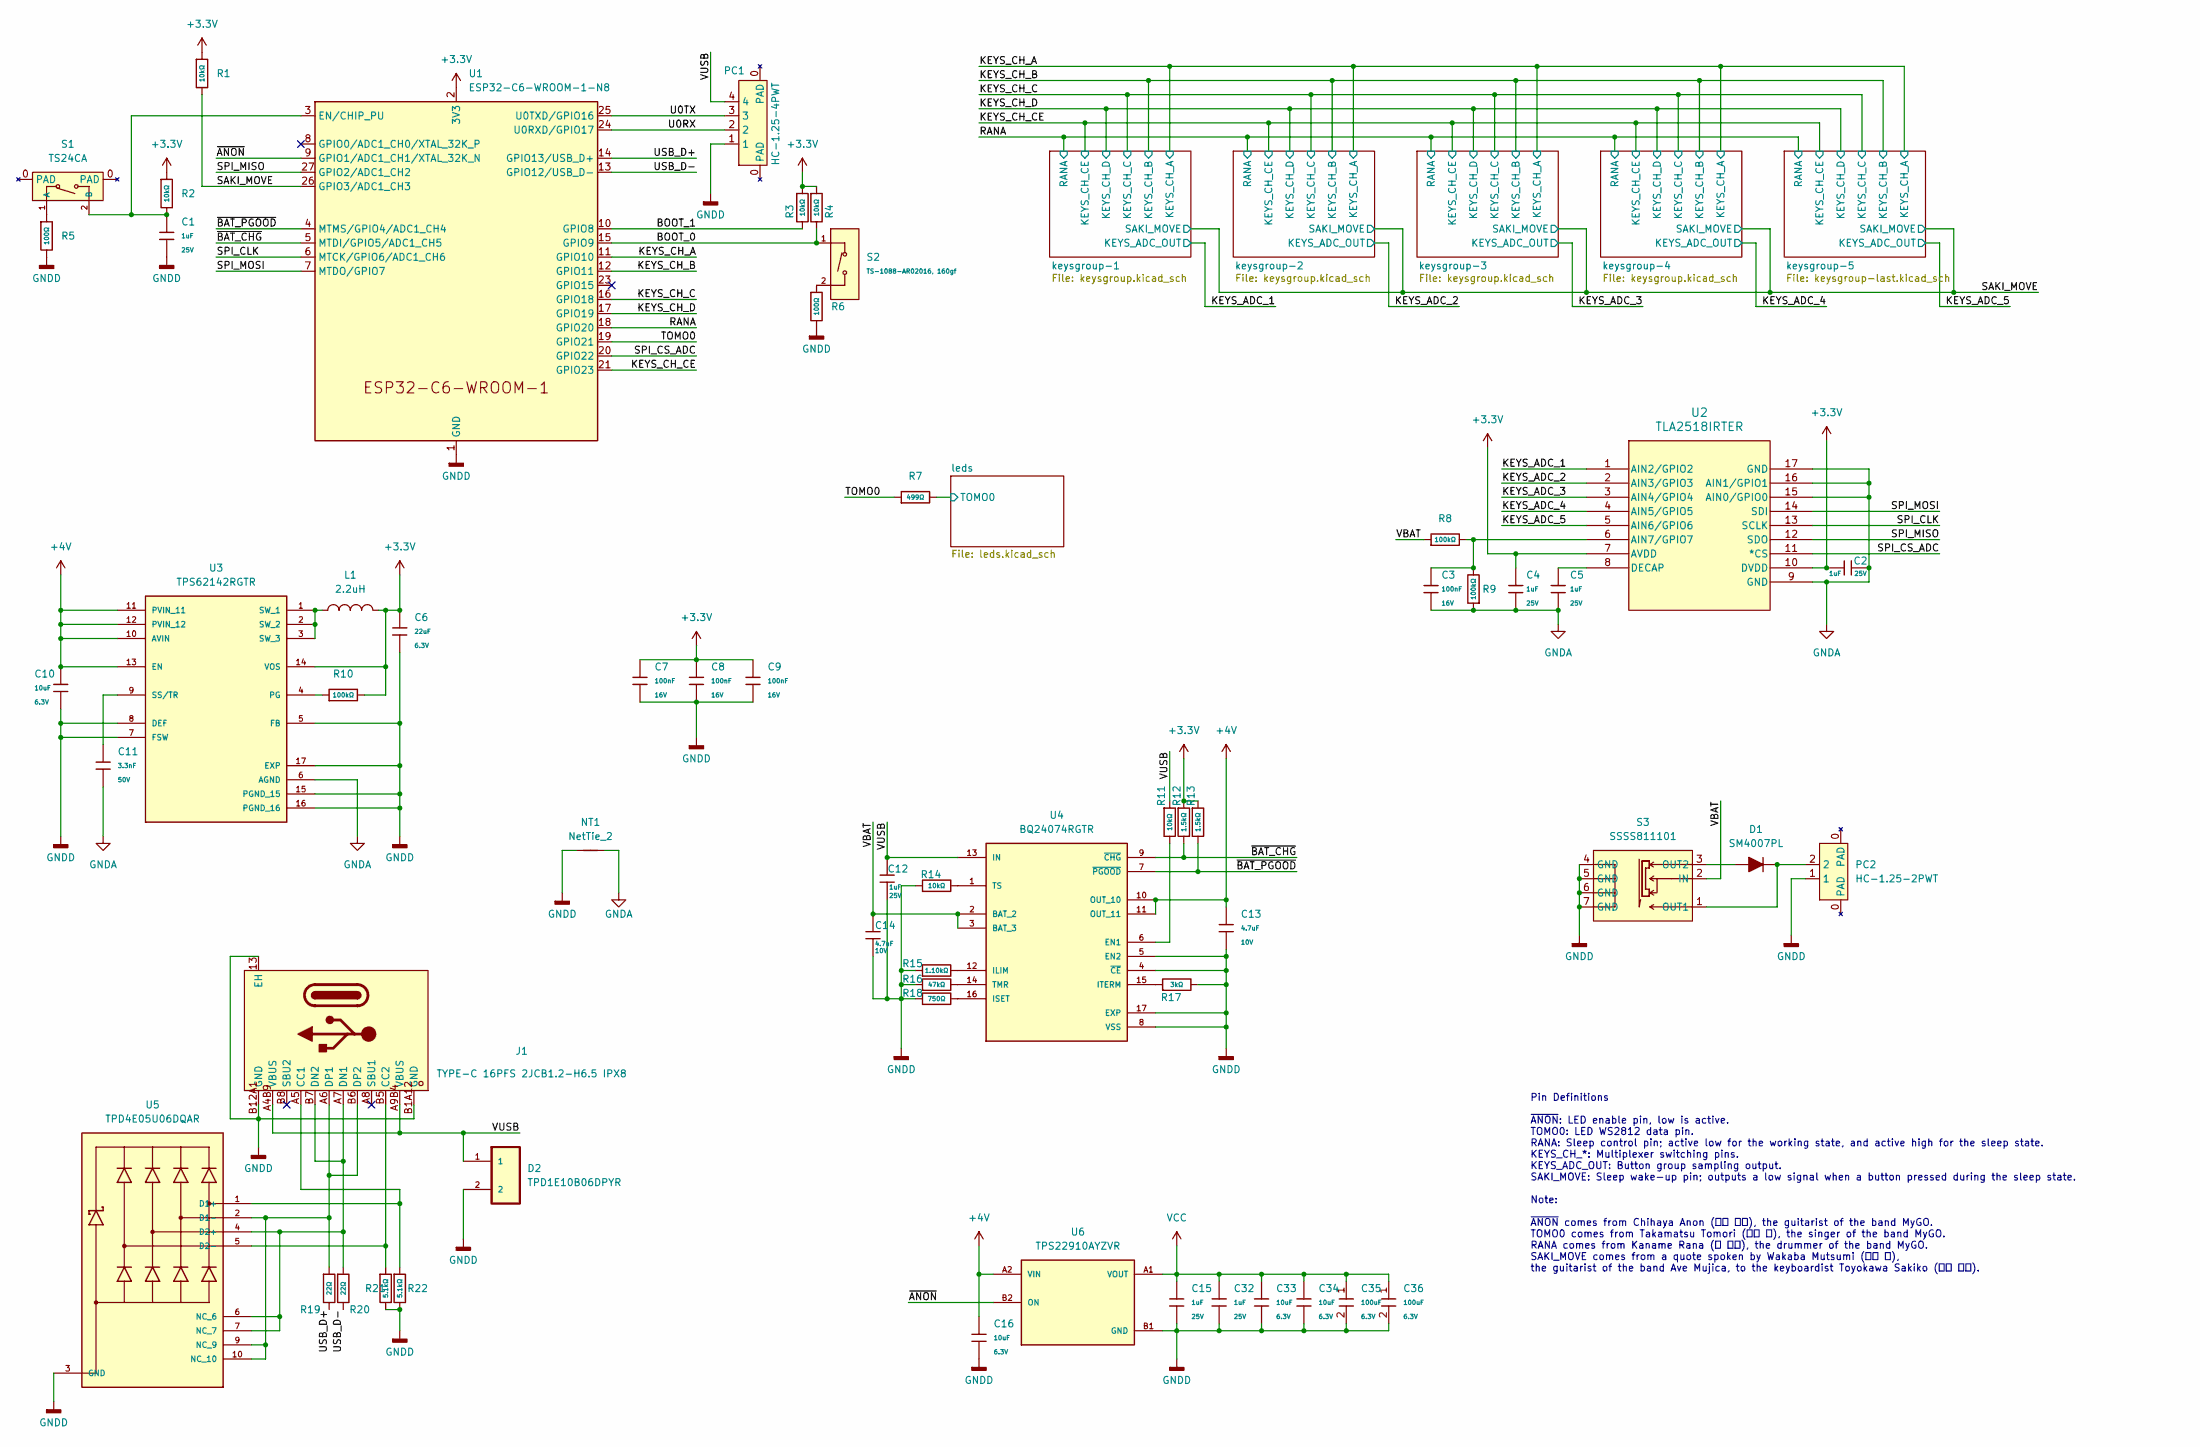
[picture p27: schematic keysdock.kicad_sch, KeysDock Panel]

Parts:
C1, C2, C4, C5, C12, C15, C32: 1uF; C_0402; Voltage Rated 25V; Tolerance ±10%; Part CL05A105KA5NQNC; LCSC C52923
C3, C7, C8, C9: 100nF; C_0402; Voltage Rated 16V; Tolerance ±10%; Part CL05B104KO5NNNC; LCSC C1525
C6: 22uF; C_0402; Voltage Rated 6.3V; Tolerance ±20%; Part CL05A226MQ5QUNC; LCSC C105226
C10, C16, C33, C34: 10uF; C_0402; Voltage Rated 6.3V; Tolerance ±20%; Part CL05A106MQ5NUNC; LCSC C15525
C11: 3.3nF; C_0402; Voltage Rated 50V; Tolerance ±10%; Part CL05B332KB5NNNC; LCSC C26404
C13, C14: 4.7uF; C_0402; Voltage Rated 10V; Tolerance ±20%; Part CL05A475MP5NRNC; LCSC C23733
C35, C36: 100uF; C_1206; Voltage Rated 6.3V; Manufacturer_Part_Number CL31A107MQHNNNE; Mouser Part Number 187-CL31A107MQHNNNE
D1: SM4007PL; D_SOD-123FL; LCSC C78741
D2: TPD1E10B06DPYR; DIO_TPD1E05U06DPYR; LCSC C48260
J1: TYPE-C 16PFS 2JCB1.2-H6.5 IPX8; USB-C-SMD_SHOUHAN_TYPE-C-16PFS-2JCB1.2-H6.5; Current Rating - Power 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 3A; LCSC C3020046
L1: 2.2uH; IND-SMD_L2.5-W2.0_MHCHL2520; Tolerance ±20%; LCSC C5832372
NT1: NetTie_2; NetTie-2_THT_Pad1.0mm
PC1: HC-1.25-4PWT; LCSC C2845381
PC2: HC-1.25-2PWT; LCSC C2845379
R1, R2, R3, R4, R11, R14: 10kΩ; R_0402; Overload Voltage (Max) 50V; Tolerance ±1%; Part 0402WGF1002TCE; LCSC C25744
R5, R6: 100Ω; R_0402; Overload Voltage (Max) 50V; Tolerance ±1%; Part 0402WGF1000TCE; LCSC C25076
R7: 499Ω; R_0402; Overload Voltage (Max) 50V; Tolerance ±1%; Part 0402WGF4990TCE; LCSC C4125
R8, R9, R10: 100kΩ; R_0402; Overload Voltage (Max) 50V; Tolerance ±1%; Part 0402WGF1003TCE; LCSC C25741
R12, R13: 1.5kΩ; R_0402; Overload Voltage (Max) 50V; Tolerance ±1%; Part 0402WGF1501TCE; LCSC C25867
R15: 1.10kΩ; R_0402; Overload Voltage (Max) 50V; Tolerance ±1%; Part 0402WGF1101TCE; LCSC C25860
R16: 47kΩ; R_0402; Overload Voltage (Max) 50V; Tolerance ±1%; Part 0402WGF4702TCE; LCSC C25792
R17: 3kΩ; R_0402; Overload Voltage (Max) 50V; Tolerance ±1%; Part 0402WGF3001TCE; LCSC C25784
R18: 750Ω; R_0402; Overload Voltage (Max) 50V; Tolerance ±1%; Part 0402WGF7500TCE; LCSC C25132
R19, R20: 22Ω; R_0402; Overload Voltage (Max) 50V; Tolerance ±1%; Part 0402WGF220JTCE; LCSC C25092
R21, R22: 5.1kΩ; R_0402; Overload Voltage (Max) 50V; Tolerance ±1%; Part 0402WGJ0512TCE; LCSC C25941
S1: TS24CA; LCSC C393942
S2: TS-1088-AR02016, 160gf; SW_TS-1088-AR02016; Voltage Rating (Dc) 12V; Part TS-1088-AR02016; LCSC C720477
S3: SSSS811101; SW-SMD_SSSS811101; LCSC C109335
U1: ESP32-C6-WROOM-1-N8; ESP32-C6-WROOM-1
U2: TLA2518IRTER; QFN50P300X300X80-17N; LCSC C1855741
U3: TPS62142RGTR; QFN50P300X300X80-17N; PARTREV E; LCSC C129331
U4: BQ24074RGTR; QFN50P300X300X80-17N; PARTREV M; LCSC C54313
U5: TPD4E05U06DQAR; IC_TPD4E05U06DQAR; PARTREV N; LCSC C138714
U6: TPS22910AYZVR; BGA4N50P2X2_88X88X50N; PARTREV F; LCSC C205966

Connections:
+3.3V: C2.1, C4.1, C6.1, C7.1, C8.1, C9.1, L1.2, R1.1, R2.1, R3.1, R4.1, R10.2, R12.1, R13.1, U1.2 (3V3), U2.7 (AVDD), U2.10 (DVDD), U3.14 (VOS); also elsewhere on the board
+4V: C10.1, C13.1, C16.1, U3.10 (AVIN), U3.11 (PVIN_11), U3.12 (PVIN_12), U3.13 (EN), U4.10 (OUT_10), U4.11 (OUT_11), U6.A2 (VIN)
/BOOT_0: R4.2, S2.1 (A), U1.15 (GPIO9)
/BOOT_1: R3.2, U1.10 (GPIO8)
/KEYS_ADC_1: U2.1 (AIN2/GPIO2); also elsewhere on the board
/KEYS_ADC_2: U2.2 (AIN3/GPIO3); also elsewhere on the board
/KEYS_ADC_3: U2.3 (AIN4/GPIO4); also elsewhere on the board
/KEYS_ADC_4: U2.4 (AIN5/GPIO5); also elsewhere on the board
/KEYS_ADC_5: U2.5 (AIN6/GPIO6); also elsewhere on the board
/KEYS_CH_A: U1.11 (GPIO10); also elsewhere on the board
/KEYS_CH_B: U1.12 (GPIO11); also elsewhere on the board
/KEYS_CH_C: U1.16 (GPIO18); also elsewhere on the board
/KEYS_CH_CE: U1.21 (GPIO23); also elsewhere on the board
/KEYS_CH_D: U1.17 (GPIO19); also elsewhere on the board
/RANA: U1.18 (GPIO20); also elsewhere on the board
/SAKI_MOVE: R1.2, U1.26 (GPIO3/ADC1_CH3); also elsewhere on the board
/SPI_CLK: U1.6 (MTCK/GPIO6/ADC1_CH6), U2.13 (SCLK)
/SPI_CS_ADC: U1.20 (GPIO22), U2.11 (*CS)
/SPI_MISO: U1.27 (GPIO2/ADC1_CH2), U2.12 (SDO)
/SPI_MOSI: U1.7 (MTDO/GPIO7), U2.14 (SDI)
/TOMO0: R7.1, U1.19 (GPIO21)
/U0RX: PC1.2, U1.24 (U0RXD/GPIO17)
/U0TX: PC1.3, U1.25 (U0TXD/GPIO16)
/USB_D+: R19.2, U1.14 (GPIO13/USB_D+)
/USB_D-: R20.2, U1.13 (GPIO12/USB_D-)
/VBAT: C14.1, R8.1, S3.2 (IN), U4.2 (BAT_2), U4.3 (BAT_3)
/VUSB: C12.1, D2.1, J1.A4B9 (VBUS), J1.A9B4 (VBUS), PC1.4, R11.1, U4.13 (IN)
/leds/TOMO0: R7.2; also elsewhere on the board
/~ANON: U1.9 (GPIO1/ADC1_CH1/XTAL_32K_N), U6.B2 (ON)
/~BAT_CHG: R12.2, U1.5 (MTDI/GPIO5/ADC1_CH5), U4.9 (~CHG)
/~BAT_PGOOD: R13.2, U1.4 (MTMS/GPIO4/ADC1_CH4), U4.7 (~PGOOD)
GNDA: C2.2, C3.2, C4.2, C5.2, C11.2, NT1.2, R9.1, U2.9 (GND), U2.15 (AIN0/GPIO0), U2.16 (AIN1/GPIO1), U2.17 (GND), U3.6 (AGND); also elsewhere on the board
GNDD: C1.2, C6.2, C7.2, C8.2, C9.2, C10.2, C12.2, C13.2, C14.2, C15.2, C16.2, C32.2, C33.2, C34.2, C35.2, C36.2, D2.2, J1.13 (EH), J1.B1A12 (GND), J1.B12A1 (GND), NT1.1, PC1.1, PC2.1, R5.2, R6.2, R14.1, R15.1, R16.1, R17.2, R18.1, R21.2, R22.2, S3.4 (GND), S3.5 (GND), S3.6 (GND), S3.7 (GND), U1.1 (GND), U1.28 (GND), U1.29 (GND), U3.5 (FB), U3.7 (FSW), U3.8 (DEF), U3.15 (PGND_15), U3.16 (PGND_16), U3.17 (EXP), U4.4 (~CE), U4.5 (EN2), U4.8 (VSS), U4.17 (EXP), U5.3 (GND), U5.8 (GND), U6.B1 (GND); also elsewhere on the board
unnamed: D1.2 (A), S3.3 (OUT2)
unnamed: D1.1 (K), PC2.2, S3.1 (OUT1)
unnamed: J1.A5 (CC1), R22.1, U5.1 (D1+)
unnamed: J1.B5 (CC2), R21.1, U5.5 (D2-)
unnamed: J1.A7 (DN1), J1.B7 (DN2), R20.1, U5.4 (D2+), U5.6 (NC_6), U5.7 (NC_7)
unnamed: J1.A6 (DP1), J1.B6 (DP2), R19.1, U5.2 (D1-), U5.9 (NC_9), U5.10 (NC_10)
unnamed: R5.1, S1.1 (A)
unnamed: C1.1, R2.2, S1.2 (B), U1.3 (EN/CHIP_PU)
unnamed: R6.1, S2.2 (B)
unnamed: C3.1, R8.2, R9.2, U2.6 (AIN7/GPIO7)
unnamed: C5.1, U2.8 (DECAP)
unnamed: R10.1, U3.4 (PG)
unnamed: C11.1, U3.9 (SS/TR)
unnamed: L1.1, U3.1 (SW_1), U3.2 (SW_2), U3.3 (SW_3)
unnamed: R11.2, U4.6 (EN1)
unnamed: R15.2, U4.12 (ILIM)
unnamed: R18.2, U4.16 (ISET)
unnamed: R17.1, U4.15 (ITERM)
unnamed: R16.2, U4.14 (TMR)
unnamed: R14.2, U4.1 (TS)
VCC: C15.1, C32.1, C33.1, C34.1, C35.1, C36.1, U6.A1 (VOUT); also elsewhere on the board

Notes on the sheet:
Pin Definitions ~{ANON}: LED enable pin, low is active. TOMO0: LED WS2812 data pin. RANA: Sleep control pin; active low for the working state, and active high for the sleep state. KEYS_CH_*: Multiplexer switching pins. KEYS_ADC_OUT: Button group sampling output. SAKI_MOVE: Sleep wake-up pin; output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

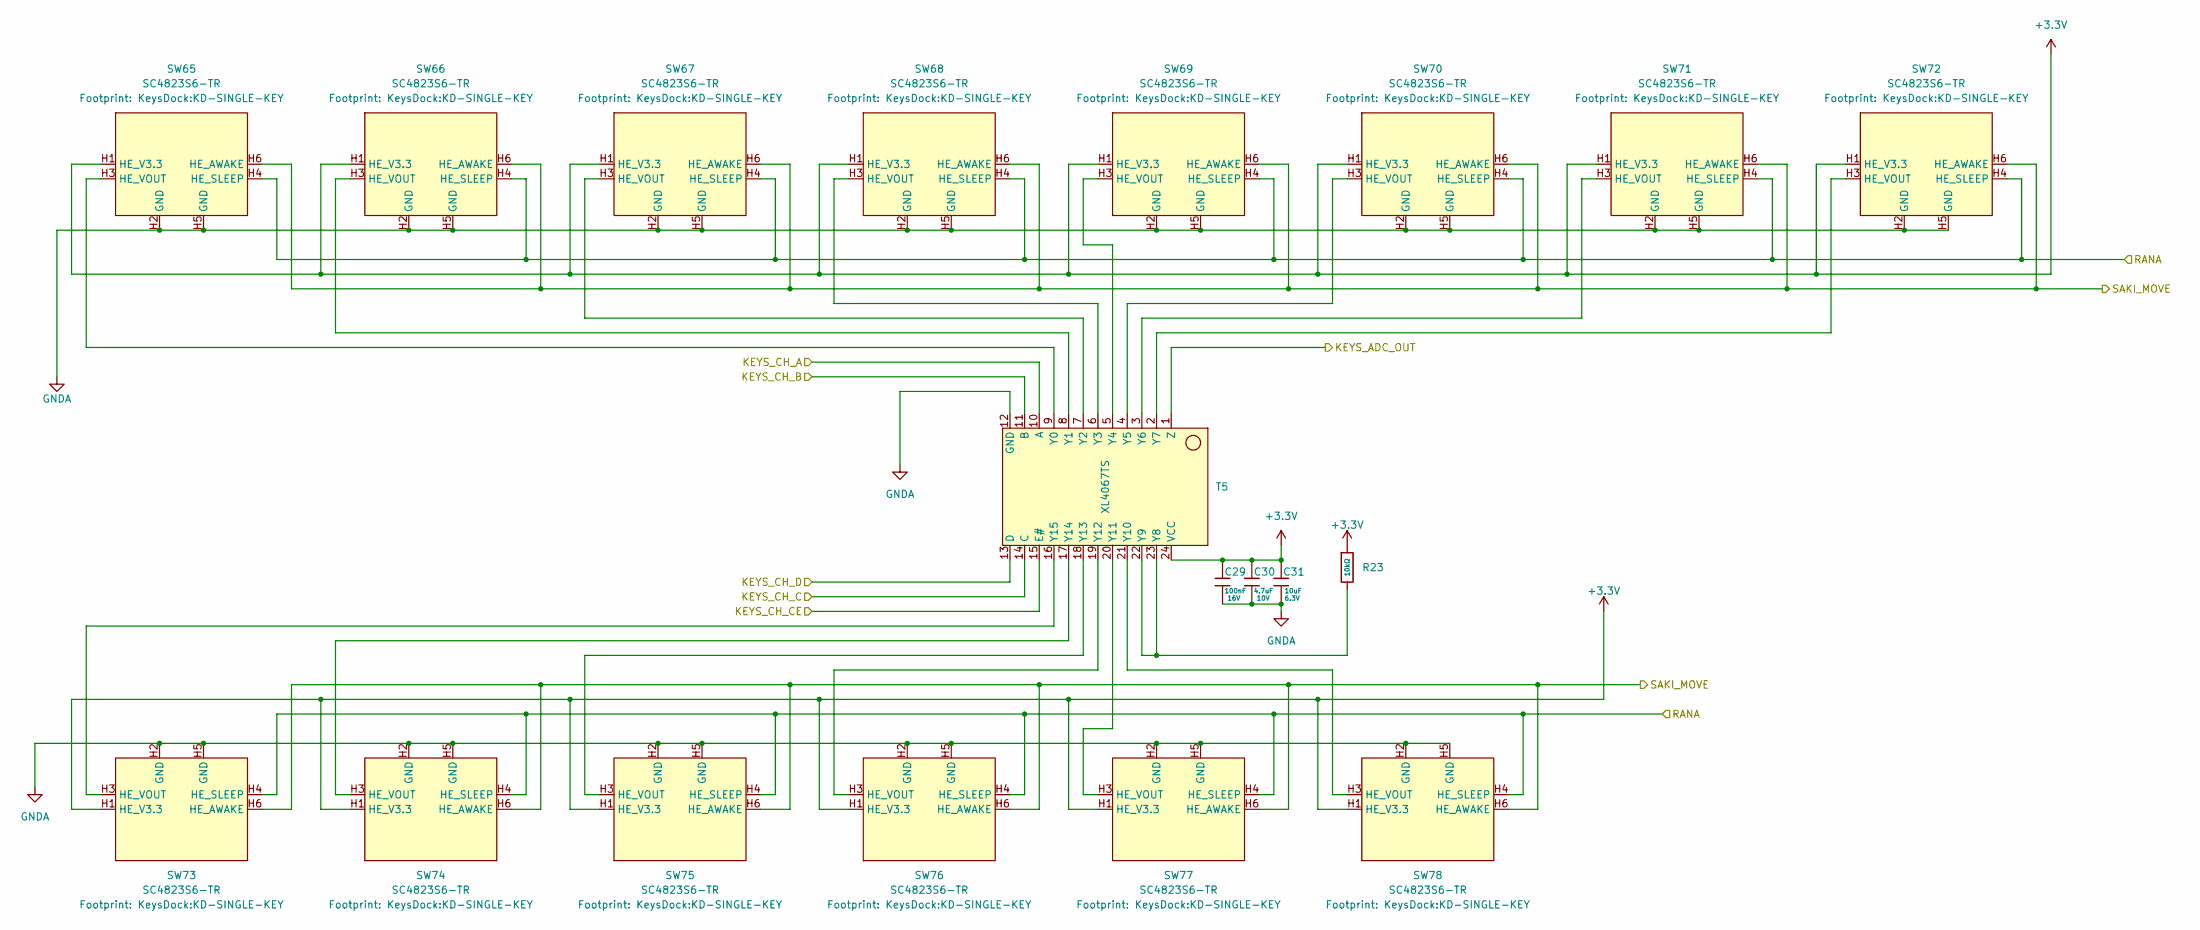
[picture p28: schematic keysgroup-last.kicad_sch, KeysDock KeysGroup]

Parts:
C29: 100nF; C_0402; Voltage Rated 16V; Tolerance ±10%; Part CL05B104KO5NNNC; LCSC C1525
C30: 4.7uF; C_0402; Voltage Rated 10V; Tolerance ±20%; Part CL05A475MP5NRNC; LCSC C23733
C31: 10uF; C_0402; Voltage Rated 6.3V; Tolerance ±20%; Part CL05A106MQ5NUNC; LCSC C15525
R23: 10kΩ; R_0402; Overload Voltage (Max) 50V; Tolerance ±1%; Part 0402WGF1002TCE; LCSC C25744
SW65, SW66, SW67, SW68, SW69, SW70, SW71, SW72, SW73, SW74, SW75, SW76, SW77, SW78: SC4823S6-TR; KD-SINGLE-KEY; LCSC C52021064
T5: XL4067TS; LCSC C41427445

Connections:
+3.3V: C29.1, C30.1, C31.1, R23.1, SW65.H1 (HE_V3.3), SW66.H1 (HE_V3.3), SW67.H1 (HE_V3.3), SW68.H1 (HE_V3.3), SW69.H1 (HE_V3.3), SW70.H1 (HE_V3.3), SW71.H1 (HE_V3.3), SW72.H1 (HE_V3.3), SW73.H1 (HE_V3.3), SW74.H1 (HE_V3.3), SW75.H1 (HE_V3.3), SW76.H1 (HE_V3.3), SW77.H1 (HE_V3.3), SW78.H1 (HE_V3.3), T5.24 (VCC); also elsewhere on the board
/KEYS_ADC_5: T5.1 (Z); also elsewhere on the board
/KEYS_CH_A: T5.10 (A); also elsewhere on the board
/KEYS_CH_B: T5.11 (B); also elsewhere on the board
/KEYS_CH_C: T5.14 (C); also elsewhere on the board
/KEYS_CH_CE: T5.15 (E#); also elsewhere on the board
/KEYS_CH_D: T5.13 (D); also elsewhere on the board
/RANA: SW65.H4 (HE_SLEEP), SW66.H4 (HE_SLEEP), SW67.H4 (HE_SLEEP), SW68.H4 (HE_SLEEP), SW69.H4 (HE_SLEEP), SW70.H4 (HE_SLEEP), SW71.H4 (HE_SLEEP), SW72.H4 (HE_SLEEP), SW73.H4 (HE_SLEEP), SW74.H4 (HE_SLEEP), SW75.H4 (HE_SLEEP), SW76.H4 (HE_SLEEP), SW77.H4 (HE_SLEEP), SW78.H4 (HE_SLEEP); also elsewhere on the board
/SAKI_MOVE: SW65.H6 (HE_AWAKE), SW66.H6 (HE_AWAKE), SW67.H6 (HE_AWAKE), SW68.H6 (HE_AWAKE), SW69.H6 (HE_AWAKE), SW70.H6 (HE_AWAKE), SW71.H6 (HE_AWAKE), SW72.H6 (HE_AWAKE), SW73.H6 (HE_AWAKE), SW74.H6 (HE_AWAKE), SW75.H6 (HE_AWAKE), SW76.H6 (HE_AWAKE), SW77.H6 (HE_AWAKE), SW78.H6 (HE_AWAKE); also elsewhere on the board
GNDA: C29.2, C30.2, C31.2, SW65.H2 (GND), SW65.H5 (GND), SW66.H2 (GND), SW66.H5 (GND), SW67.H2 (GND), SW67.H5 (GND), SW68.H2 (GND), SW68.H5 (GND), SW69.H2 (GND), SW69.H5 (GND), SW70.H2 (GND), SW70.H5 (GND), SW71.H2 (GND), SW71.H5 (GND), SW72.H2 (GND), SW72.H5 (GND), SW73.H2 (GND), SW73.H5 (GND), SW74.H2 (GND), SW74.H5 (GND), SW75.H2 (GND), SW75.H5 (GND), SW76.H2 (GND), SW76.H5 (GND), SW77.H2 (GND), SW77.H5 (GND), SW78.H2 (GND), SW78.H5 (GND), T5.12 (GND); also elsewhere on the board
unnamed: SW65.H3 (HE_VOUT), T5.9 (Y0)
unnamed: SW66.H3 (HE_VOUT), T5.8 (Y1)
unnamed: SW67.H3 (HE_VOUT), T5.7 (Y2)
unnamed: SW68.H3 (HE_VOUT), T5.6 (Y3)
unnamed: SW69.H3 (HE_VOUT), T5.5 (Y4)
unnamed: SW70.H3 (HE_VOUT), T5.4 (Y5)
unnamed: SW71.H3 (HE_VOUT), T5.3 (Y6)
unnamed: SW72.H3 (HE_VOUT), T5.2 (Y7)
unnamed: SW73.H3 (HE_VOUT), T5.16 (Y15)
unnamed: SW74.H3 (HE_VOUT), T5.17 (Y14)
unnamed: SW75.H3 (HE_VOUT), T5.18 (Y13)
unnamed: SW76.H3 (HE_VOUT), T5.19 (Y12)
unnamed: SW77.H3 (HE_VOUT), T5.20 (Y11)
unnamed: SW78.H3 (HE_VOUT), T5.21 (Y10)
unnamed: R23.2, T5.22 (Y9), T5.23 (Y8)

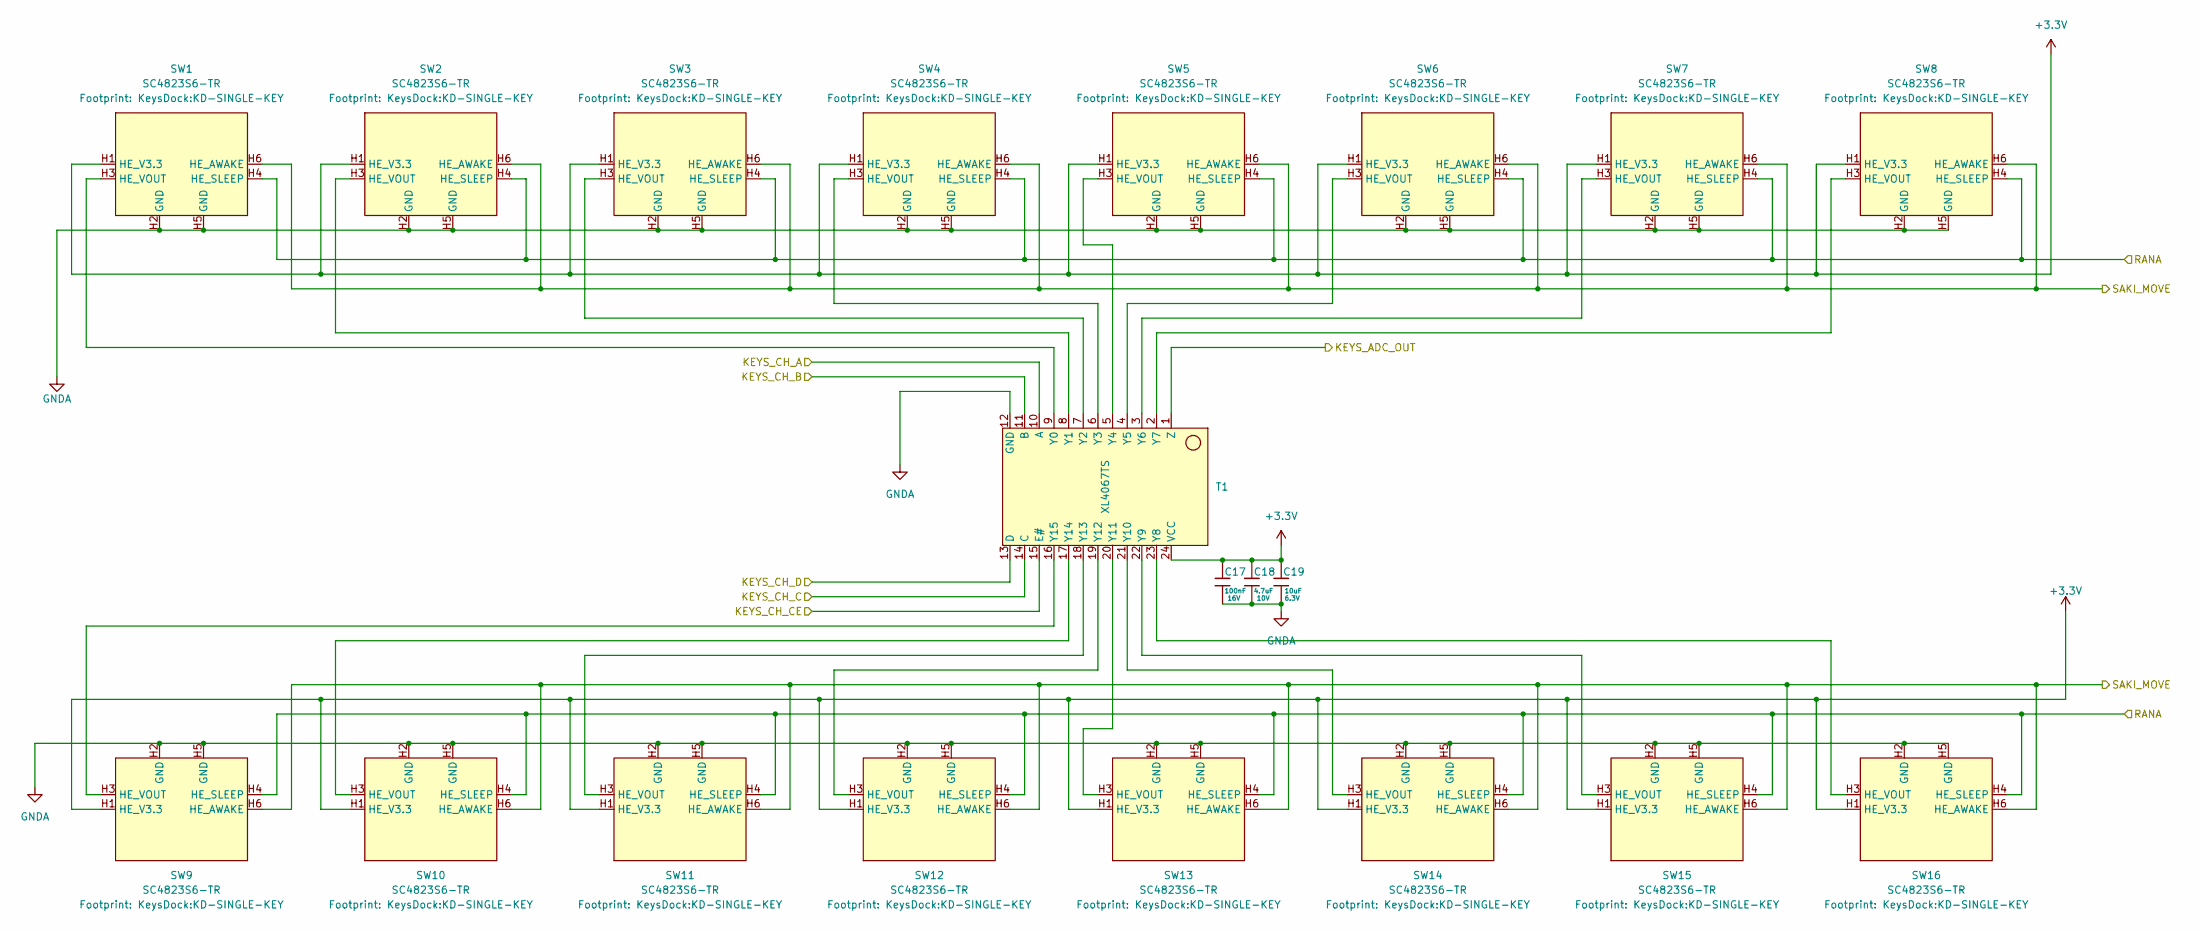
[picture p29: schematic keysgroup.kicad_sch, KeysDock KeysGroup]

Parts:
C17: 100nF; C_0402; Voltage Rated 16V; Tolerance ±10%; Part CL05B104KO5NNNC; LCSC C1525
C18: 4.7uF; C_0402; Voltage Rated 10V; Tolerance ±20%; Part CL05A475MP5NRNC; LCSC C23733
C19: 10uF; C_0402; Voltage Rated 6.3V; Tolerance ±20%; Part CL05A106MQ5NUNC; LCSC C15525
SW1, SW2, SW3, SW4, SW5, SW6, SW7, SW8, SW9, SW10, SW11, SW12, SW13, SW14, SW15, SW16: SC4823S6-TR; KD-SINGLE-KEY; LCSC C52021064
T1: XL4067TS; LCSC C41427445

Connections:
+3.3V: C17.1, C18.1, C19.1, SW1.H1 (HE_V3.3), SW2.H1 (HE_V3.3), SW3.H1 (HE_V3.3), SW4.H1 (HE_V3.3), SW5.H1 (HE_V3.3), SW6.H1 (HE_V3.3), SW7.H1 (HE_V3.3), SW8.H1 (HE_V3.3), SW9.H1 (HE_V3.3), SW10.H1 (HE_V3.3), SW11.H1 (HE_V3.3), SW12.H1 (HE_V3.3), SW13.H1 (HE_V3.3), SW14.H1 (HE_V3.3), SW15.H1 (HE_V3.3), SW16.H1 (HE_V3.3), T1.24 (VCC); also elsewhere on the board
/KEYS_ADC_1: T1.1 (Z); also elsewhere on the board
/KEYS_CH_A: T1.10 (A); also elsewhere on the board
/KEYS_CH_B: T1.11 (B); also elsewhere on the board
/KEYS_CH_C: T1.14 (C); also elsewhere on the board
/KEYS_CH_CE: T1.15 (E#); also elsewhere on the board
/KEYS_CH_D: T1.13 (D); also elsewhere on the board
/RANA: SW1.H4 (HE_SLEEP), SW2.H4 (HE_SLEEP), SW3.H4 (HE_SLEEP), SW4.H4 (HE_SLEEP), SW5.H4 (HE_SLEEP), SW6.H4 (HE_SLEEP), SW7.H4 (HE_SLEEP), SW8.H4 (HE_SLEEP), SW9.H4 (HE_SLEEP), SW10.H4 (HE_SLEEP), SW11.H4 (HE_SLEEP), SW12.H4 (HE_SLEEP), SW13.H4 (HE_SLEEP), SW14.H4 (HE_SLEEP), SW15.H4 (HE_SLEEP), SW16.H4 (HE_SLEEP); also elsewhere on the board
/SAKI_MOVE: SW1.H6 (HE_AWAKE), SW2.H6 (HE_AWAKE), SW3.H6 (HE_AWAKE), SW4.H6 (HE_AWAKE), SW5.H6 (HE_AWAKE), SW6.H6 (HE_AWAKE), SW7.H6 (HE_AWAKE), SW8.H6 (HE_AWAKE), SW9.H6 (HE_AWAKE), SW10.H6 (HE_AWAKE), SW11.H6 (HE_AWAKE), SW12.H6 (HE_AWAKE), SW13.H6 (HE_AWAKE), SW14.H6 (HE_AWAKE), SW15.H6 (HE_AWAKE), SW16.H6 (HE_AWAKE); also elsewhere on the board
GNDA: C17.2, C18.2, C19.2, SW1.H2 (GND), SW1.H5 (GND), SW2.H2 (GND), SW2.H5 (GND), SW3.H2 (GND), SW3.H5 (GND), SW4.H2 (GND), SW4.H5 (GND), SW5.H2 (GND), SW5.H5 (GND), SW6.H2 (GND), SW6.H5 (GND), SW7.H2 (GND), SW7.H5 (GND), SW8.H2 (GND), SW8.H5 (GND), SW9.H2 (GND), SW9.H5 (GND), SW10.H2 (GND), SW10.H5 (GND), SW11.H2 (GND), SW11.H5 (GND), SW12.H2 (GND), SW12.H5 (GND), SW13.H2 (GND), SW13.H5 (GND), SW14.H2 (GND), SW14.H5 (GND), SW15.H2 (GND), SW15.H5 (GND), SW16.H2 (GND), SW16.H5 (GND), T1.12 (GND); also elsewhere on the board
unnamed: SW1.H3 (HE_VOUT), T1.9 (Y0)
unnamed: SW2.H3 (HE_VOUT), T1.8 (Y1)
unnamed: SW3.H3 (HE_VOUT), T1.7 (Y2)
unnamed: SW4.H3 (HE_VOUT), T1.6 (Y3)
unnamed: SW5.H3 (HE_VOUT), T1.5 (Y4)
unnamed: SW6.H3 (HE_VOUT), T1.4 (Y5)
unnamed: SW7.H3 (HE_VOUT), T1.3 (Y6)
unnamed: SW8.H3 (HE_VOUT), T1.2 (Y7)
unnamed: SW9.H3 (HE_VOUT), T1.16 (Y15)
unnamed: SW10.H3 (HE_VOUT), T1.17 (Y14)
unnamed: SW11.H3 (HE_VOUT), T1.18 (Y13)
unnamed: SW12.H3 (HE_VOUT), T1.19 (Y12)
unnamed: SW13.H3 (HE_VOUT), T1.20 (Y11)
unnamed: SW14.H3 (HE_VOUT), T1.21 (Y10)
unnamed: SW15.H3 (HE_VOUT), T1.22 (Y9)
unnamed: SW16.H3 (HE_VOUT), T1.23 (Y8)

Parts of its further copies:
C20, C23, C26: 100nF; C_0402; Voltage Rated 16V; Tolerance ±10%; Part CL05B104KO5NNNC; LCSC C1525
C21, C24, C27: 4.7uF; C_0402; Voltage Rated 10V; Tolerance ±20%; Part CL05A475MP5NRNC; LCSC C23733
C22, C25, C28: 10uF; C_0402; Voltage Rated 6.3V; Tolerance ±20%; Part CL05A106MQ5NUNC; LCSC C15525
SW17, SW18, SW19, SW20, SW21, SW22, SW23, SW24, SW25, SW26, SW27, SW28, SW29, SW30, SW31, SW32, SW33, SW34, SW35, SW36, SW37, SW38, SW39, SW40, SW41, SW42, SW43, SW44, SW45, SW46, SW47, SW48, SW49, SW50, SW51, SW52, SW53, SW54, SW55, SW56, SW57, SW58, SW59, SW60, SW61, SW62, SW63, SW64: SC4823S6-TR; KD-SINGLE-KEY; LCSC C52021064
T2, T3, T4: XL4067TS; LCSC C41427445

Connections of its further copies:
+3.3V: C20.1, C21.1, C22.1, C23.1, C24.1, C25.1, C26.1, C27.1, C28.1, SW17.H1 (HE_V3.3), SW18.H1 (HE_V3.3), SW19.H1 (HE_V3.3), SW20.H1 (HE_V3.3), SW21.H1 (HE_V3.3), SW22.H1 (HE_V3.3), SW23.H1 (HE_V3.3), SW24.H1 (HE_V3.3), SW25.H1 (HE_V3.3), SW26.H1 (HE_V3.3), SW27.H1 (HE_V3.3), SW28.H1 (HE_V3.3), SW29.H1 (HE_V3.3), SW30.H1 (HE_V3.3), SW31.H1 (HE_V3.3), SW32.H1 (HE_V3.3), SW33.H1 (HE_V3.3), SW34.H1 (HE_V3.3), SW35.H1 (HE_V3.3), SW36.H1 (HE_V3.3), SW37.H1 (HE_V3.3), SW38.H1 (HE_V3.3), SW39.H1 (HE_V3.3), SW40.H1 (HE_V3.3), SW41.H1 (HE_V3.3), SW42.H1 (HE_V3.3), SW43.H1 (HE_V3.3), SW44.H1 (HE_V3.3), SW45.H1 (HE_V3.3), SW46.H1 (HE_V3.3), SW47.H1 (HE_V3.3), SW48.H1 (HE_V3.3), SW49.H1 (HE_V3.3), SW50.H1 (HE_V3.3), SW51.H1 (HE_V3.3), SW52.H1 (HE_V3.3), SW53.H1 (HE_V3.3), SW54.H1 (HE_V3.3), SW55.H1 (HE_V3.3), SW56.H1 (HE_V3.3), SW57.H1 (HE_V3.3), SW58.H1 (HE_V3.3), SW59.H1 (HE_V3.3), SW60.H1 (HE_V3.3), SW61.H1 (HE_V3.3), SW62.H1 (HE_V3.3), SW63.H1 (HE_V3.3), SW64.H1 (HE_V3.3), T2.24 (VCC), T3.24 (VCC), T4.24 (VCC); also elsewhere on the board
/KEYS_ADC_2: T2.1 (Z); also elsewhere on the board
/KEYS_ADC_3: T3.1 (Z); also elsewhere on the board
/KEYS_ADC_4: T4.1 (Z); also elsewhere on the board
/KEYS_CH_A: T2.10 (A), T3.10 (A), T4.10 (A); also elsewhere on the board
/KEYS_CH_B: T2.11 (B), T3.11 (B), T4.11 (B); also elsewhere on the board
/KEYS_CH_C: T2.14 (C), T3.14 (C), T4.14 (C); also elsewhere on the board
/KEYS_CH_CE: T2.15 (E#), T3.15 (E#), T4.15 (E#); also elsewhere on the board
/KEYS_CH_D: T2.13 (D), T3.13 (D), T4.13 (D); also elsewhere on the board
/RANA: SW17.H4 (HE_SLEEP), SW18.H4 (HE_SLEEP), SW19.H4 (HE_SLEEP), SW20.H4 (HE_SLEEP), SW21.H4 (HE_SLEEP), SW22.H4 (HE_SLEEP), SW23.H4 (HE_SLEEP), SW24.H4 (HE_SLEEP), SW25.H4 (HE_SLEEP), SW26.H4 (HE_SLEEP), SW27.H4 (HE_SLEEP), SW28.H4 (HE_SLEEP), SW29.H4 (HE_SLEEP), SW30.H4 (HE_SLEEP), SW31.H4 (HE_SLEEP), SW32.H4 (HE_SLEEP), SW33.H4 (HE_SLEEP), SW34.H4 (HE_SLEEP), SW35.H4 (HE_SLEEP), SW36.H4 (HE_SLEEP), SW37.H4 (HE_SLEEP), SW38.H4 (HE_SLEEP), SW39.H4 (HE_SLEEP), SW40.H4 (HE_SLEEP), SW41.H4 (HE_SLEEP), SW42.H4 (HE_SLEEP), SW43.H4 (HE_SLEEP), SW44.H4 (HE_SLEEP), SW45.H4 (HE_SLEEP), SW46.H4 (HE_SLEEP), SW47.H4 (HE_SLEEP), SW48.H4 (HE_SLEEP), SW49.H4 (HE_SLEEP), SW50.H4 (HE_SLEEP), SW51.H4 (HE_SLEEP), SW52.H4 (HE_SLEEP), SW53.H4 (HE_SLEEP), SW54.H4 (HE_SLEEP), SW55.H4 (HE_SLEEP), SW56.H4 (HE_SLEEP), SW57.H4 (HE_SLEEP), SW58.H4 (HE_SLEEP), SW59.H4 (HE_SLEEP), SW60.H4 (HE_SLEEP), SW61.H4 (HE_SLEEP), SW62.H4 (HE_SLEEP), SW63.H4 (HE_SLEEP), SW64.H4 (HE_SLEEP); also elsewhere on the board
/SAKI_MOVE: SW17.H6 (HE_AWAKE), SW18.H6 (HE_AWAKE), SW19.H6 (HE_AWAKE), SW20.H6 (HE_AWAKE), SW21.H6 (HE_AWAKE), SW22.H6 (HE_AWAKE), SW23.H6 (HE_AWAKE), SW24.H6 (HE_AWAKE), SW25.H6 (HE_AWAKE), SW26.H6 (HE_AWAKE), SW27.H6 (HE_AWAKE), SW28.H6 (HE_AWAKE), SW29.H6 (HE_AWAKE), SW30.H6 (HE_AWAKE), SW31.H6 (HE_AWAKE), SW32.H6 (HE_AWAKE), SW33.H6 (HE_AWAKE), SW34.H6 (HE_AWAKE), SW35.H6 (HE_AWAKE), SW36.H6 (HE_AWAKE), SW37.H6 (HE_AWAKE), SW38.H6 (HE_AWAKE), SW39.H6 (HE_AWAKE), SW40.H6 (HE_AWAKE), SW41.H6 (HE_AWAKE), SW42.H6 (HE_AWAKE), SW43.H6 (HE_AWAKE), SW44.H6 (HE_AWAKE), SW45.H6 (HE_AWAKE), SW46.H6 (HE_AWAKE), SW47.H6 (HE_AWAKE), SW48.H6 (HE_AWAKE), SW49.H6 (HE_AWAKE), SW50.H6 (HE_AWAKE), SW51.H6 (HE_AWAKE), SW52.H6 (HE_AWAKE), SW53.H6 (HE_AWAKE), SW54.H6 (HE_AWAKE), SW55.H6 (HE_AWAKE), SW56.H6 (HE_AWAKE), SW57.H6 (HE_AWAKE), SW58.H6 (HE_AWAKE), SW59.H6 (HE_AWAKE), SW60.H6 (HE_AWAKE), SW61.H6 (HE_AWAKE), SW62.H6 (HE_AWAKE), SW63.H6 (HE_AWAKE), SW64.H6 (HE_AWAKE); also elsewhere on the board
GNDA: C20.2, C21.2, C22.2, C23.2, C24.2, C25.2, C26.2, C27.2, C28.2, SW17.H2 (GND), SW17.H5 (GND), SW18.H2 (GND), SW18.H5 (GND), SW19.H2 (GND), SW19.H5 (GND), SW20.H2 (GND), SW20.H5 (GND), SW21.H2 (GND), SW21.H5 (GND), SW22.H2 (GND), SW22.H5 (GND), SW23.H2 (GND), SW23.H5 (GND), SW24.H2 (GND), SW24.H5 (GND), SW25.H2 (GND), SW25.H5 (GND), SW26.H2 (GND), SW26.H5 (GND), SW27.H2 (GND), SW27.H5 (GND), SW28.H2 (GND), SW28.H5 (GND), SW29.H2 (GND), SW29.H5 (GND), SW30.H2 (GND), SW30.H5 (GND), SW31.H2 (GND), SW31.H5 (GND), SW32.H2 (GND), SW32.H5 (GND), SW33.H2 (GND), SW33.H5 (GND), SW34.H2 (GND), SW34.H5 (GND), SW35.H2 (GND), SW35.H5 (GND), SW36.H2 (GND), SW36.H5 (GND), SW37.H2 (GND), SW37.H5 (GND), SW38.H2 (GND), SW38.H5 (GND), SW39.H2 (GND), SW39.H5 (GND), SW40.H2 (GND), SW40.H5 (GND), SW41.H2 (GND), SW41.H5 (GND), SW42.H2 (GND), SW42.H5 (GND), SW43.H2 (GND), SW43.H5 (GND), SW44.H2 (GND), SW44.H5 (GND), SW45.H2 (GND), SW45.H5 (GND), SW46.H2 (GND), SW46.H5 (GND), SW47.H2 (GND), SW47.H5 (GND), SW48.H2 (GND), SW48.H5 (GND), SW49.H2 (GND), SW49.H5 (GND), SW50.H2 (GND), SW50.H5 (GND), SW51.H2 (GND), SW51.H5 (GND), SW52.H2 (GND), SW52.H5 (GND), SW53.H2 (GND), SW53.H5 (GND), SW54.H2 (GND), SW54.H5 (GND), SW55.H2 (GND), SW55.H5 (GND), SW56.H2 (GND), SW56.H5 (GND), SW57.H2 (GND), SW57.H5 (GND), SW58.H2 (GND), SW58.H5 (GND), SW59.H2 (GND), SW59.H5 (GND), SW60.H2 (GND), SW60.H5 (GND), SW61.H2 (GND), SW61.H5 (GND), SW62.H2 (GND), SW62.H5 (GND), SW63.H2 (GND), SW63.H5 (GND), SW64.H2 (GND), SW64.H5 (GND), T2.12 (GND), T3.12 (GND), T4.12 (GND); also elsewhere on the board
unnamed: SW17.H3 (HE_VOUT), T2.9 (Y0)
unnamed: SW18.H3 (HE_VOUT), T2.8 (Y1)
unnamed: SW19.H3 (HE_VOUT), T2.7 (Y2)
unnamed: SW20.H3 (HE_VOUT), T2.6 (Y3)
unnamed: SW21.H3 (HE_VOUT), T2.5 (Y4)
unnamed: SW22.H3 (HE_VOUT), T2.4 (Y5)
unnamed: SW23.H3 (HE_VOUT), T2.3 (Y6)
unnamed: SW24.H3 (HE_VOUT), T2.2 (Y7)
unnamed: SW25.H3 (HE_VOUT), T2.16 (Y15)
unnamed: SW26.H3 (HE_VOUT), T2.17 (Y14)
unnamed: SW27.H3 (HE_VOUT), T2.18 (Y13)
unnamed: SW28.H3 (HE_VOUT), T2.19 (Y12)
unnamed: SW29.H3 (HE_VOUT), T2.20 (Y11)
unnamed: SW30.H3 (HE_VOUT), T2.21 (Y10)
unnamed: SW31.H3 (HE_VOUT), T2.22 (Y9)
unnamed: SW32.H3 (HE_VOUT), T2.23 (Y8)
unnamed: SW33.H3 (HE_VOUT), T3.9 (Y0)
unnamed: SW34.H3 (HE_VOUT), T3.8 (Y1)
unnamed: SW35.H3 (HE_VOUT), T3.7 (Y2)
unnamed: SW36.H3 (HE_VOUT), T3.6 (Y3)
unnamed: SW37.H3 (HE_VOUT), T3.5 (Y4)
unnamed: SW38.H3 (HE_VOUT), T3.4 (Y5)
unnamed: SW39.H3 (HE_VOUT), T3.3 (Y6)
unnamed: SW40.H3 (HE_VOUT), T3.2 (Y7)
unnamed: SW41.H3 (HE_VOUT), T3.16 (Y15)
unnamed: SW42.H3 (HE_VOUT), T3.17 (Y14)
unnamed: SW43.H3 (HE_VOUT), T3.18 (Y13)
unnamed: SW44.H3 (HE_VOUT), T3.19 (Y12)
unnamed: SW45.H3 (HE_VOUT), T3.20 (Y11)
unnamed: SW46.H3 (HE_VOUT), T3.21 (Y10)
unnamed: SW47.H3 (HE_VOUT), T3.22 (Y9)
unnamed: SW48.H3 (HE_VOUT), T3.23 (Y8)
unnamed: SW49.H3 (HE_VOUT), T4.9 (Y0)
unnamed: SW50.H3 (HE_VOUT), T4.8 (Y1)
unnamed: SW51.H3 (HE_VOUT), T4.7 (Y2)
unnamed: SW52.H3 (HE_VOUT), T4.6 (Y3)
unnamed: SW53.H3 (HE_VOUT), T4.5 (Y4)
unnamed: SW54.H3 (HE_VOUT), T4.4 (Y5)
unnamed: SW55.H3 (HE_VOUT), T4.3 (Y6)
unnamed: SW56.H3 (HE_VOUT), T4.2 (Y7)
unnamed: SW57.H3 (HE_VOUT), T4.16 (Y15)
unnamed: SW58.H3 (HE_VOUT), T4.17 (Y14)
unnamed: SW59.H3 (HE_VOUT), T4.18 (Y13)
unnamed: SW60.H3 (HE_VOUT), T4.19 (Y12)
unnamed: SW61.H3 (HE_VOUT), T4.20 (Y11)
unnamed: SW62.H3 (HE_VOUT), T4.21 (Y10)
unnamed: SW63.H3 (HE_VOUT), T4.22 (Y9)
unnamed: SW64.H3 (HE_VOUT), T4.23 (Y8)

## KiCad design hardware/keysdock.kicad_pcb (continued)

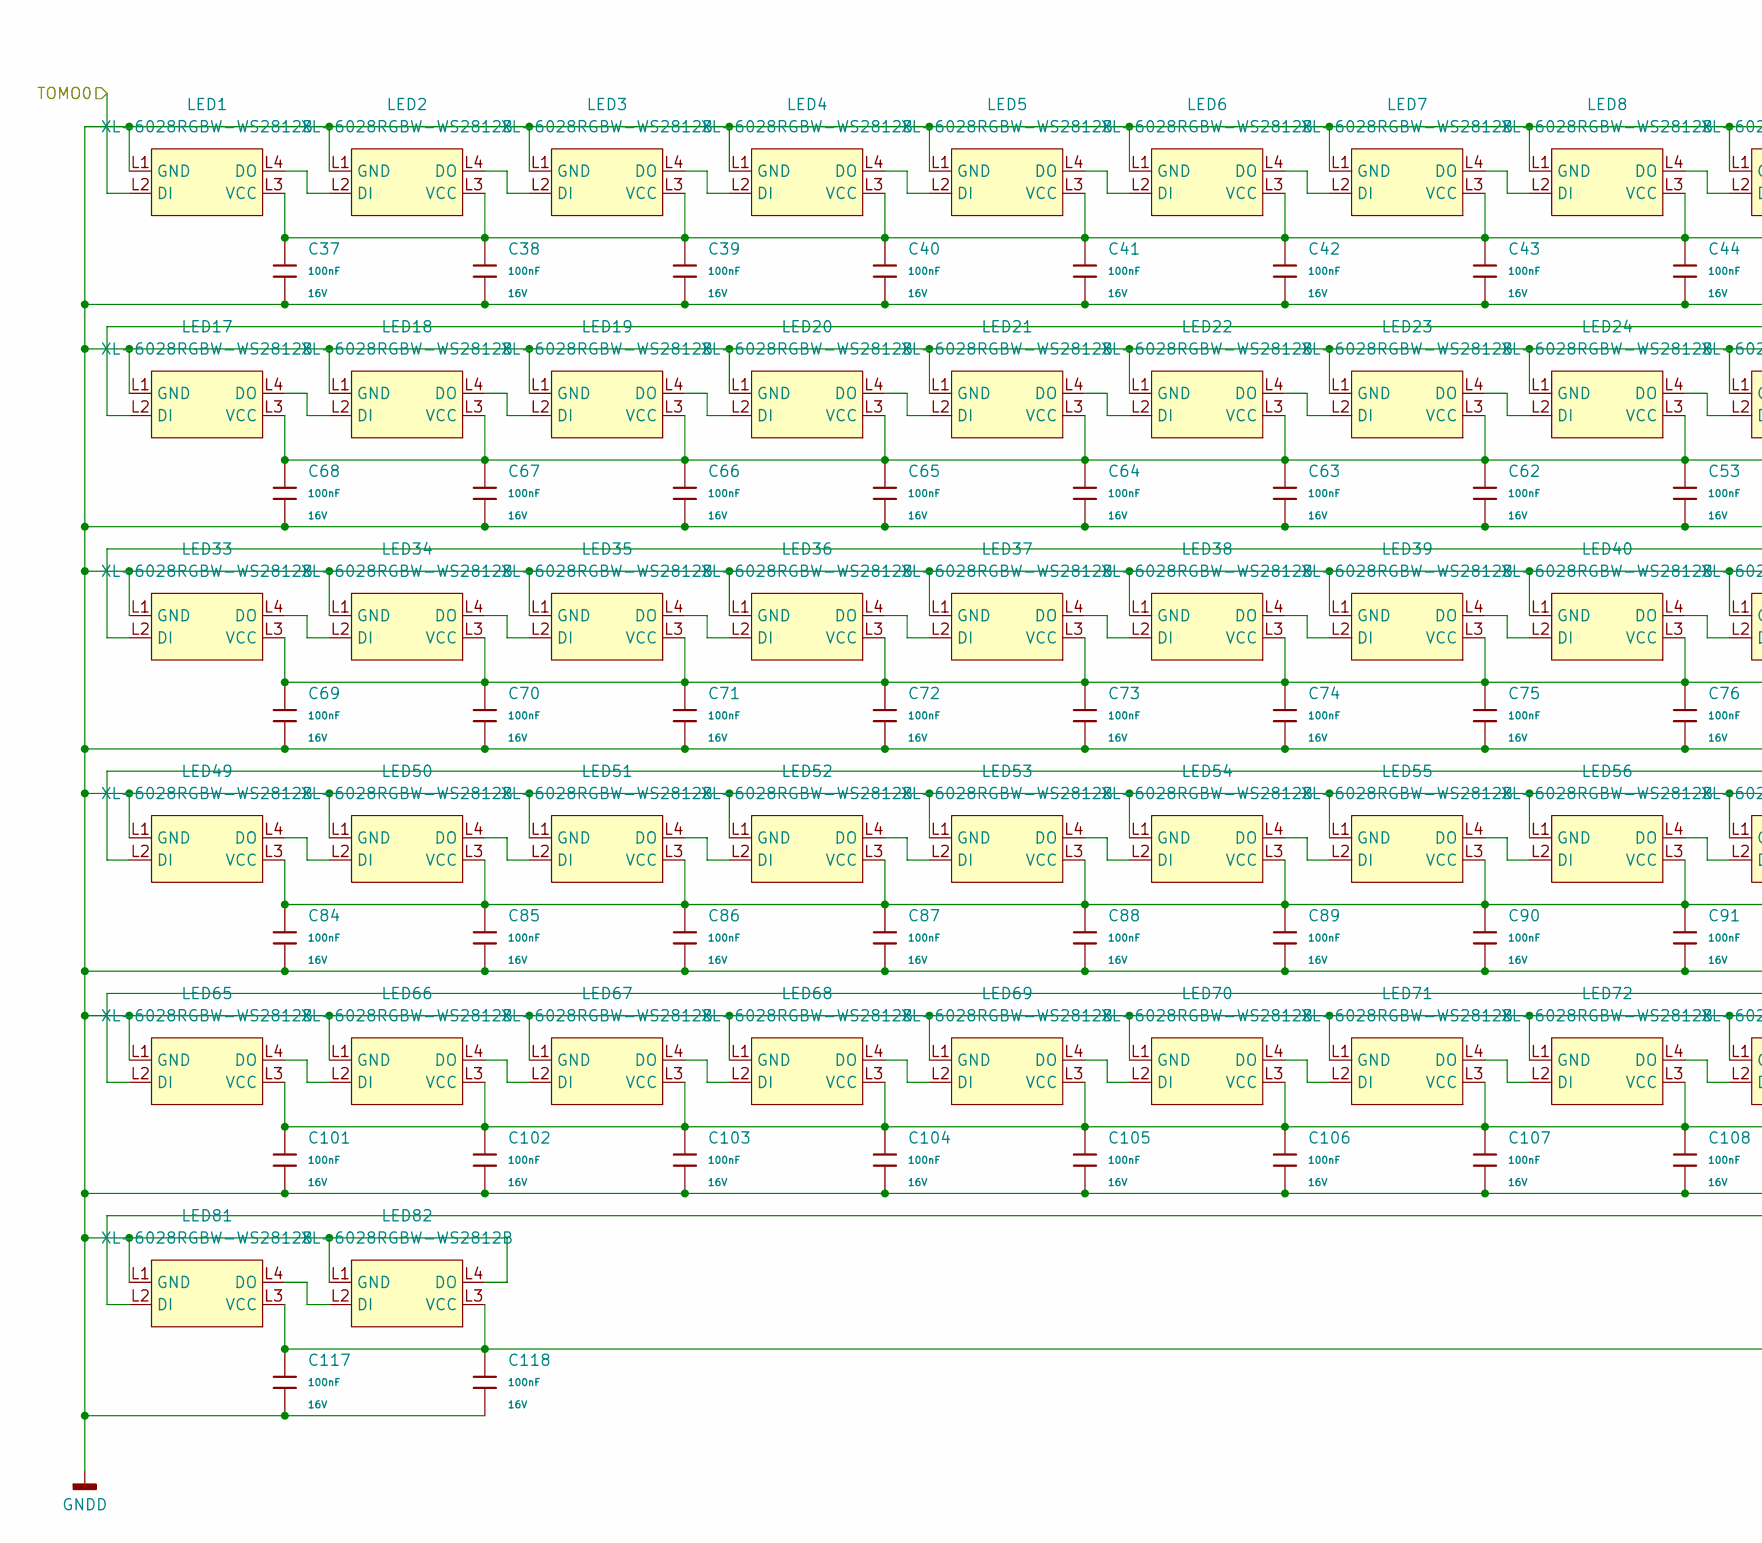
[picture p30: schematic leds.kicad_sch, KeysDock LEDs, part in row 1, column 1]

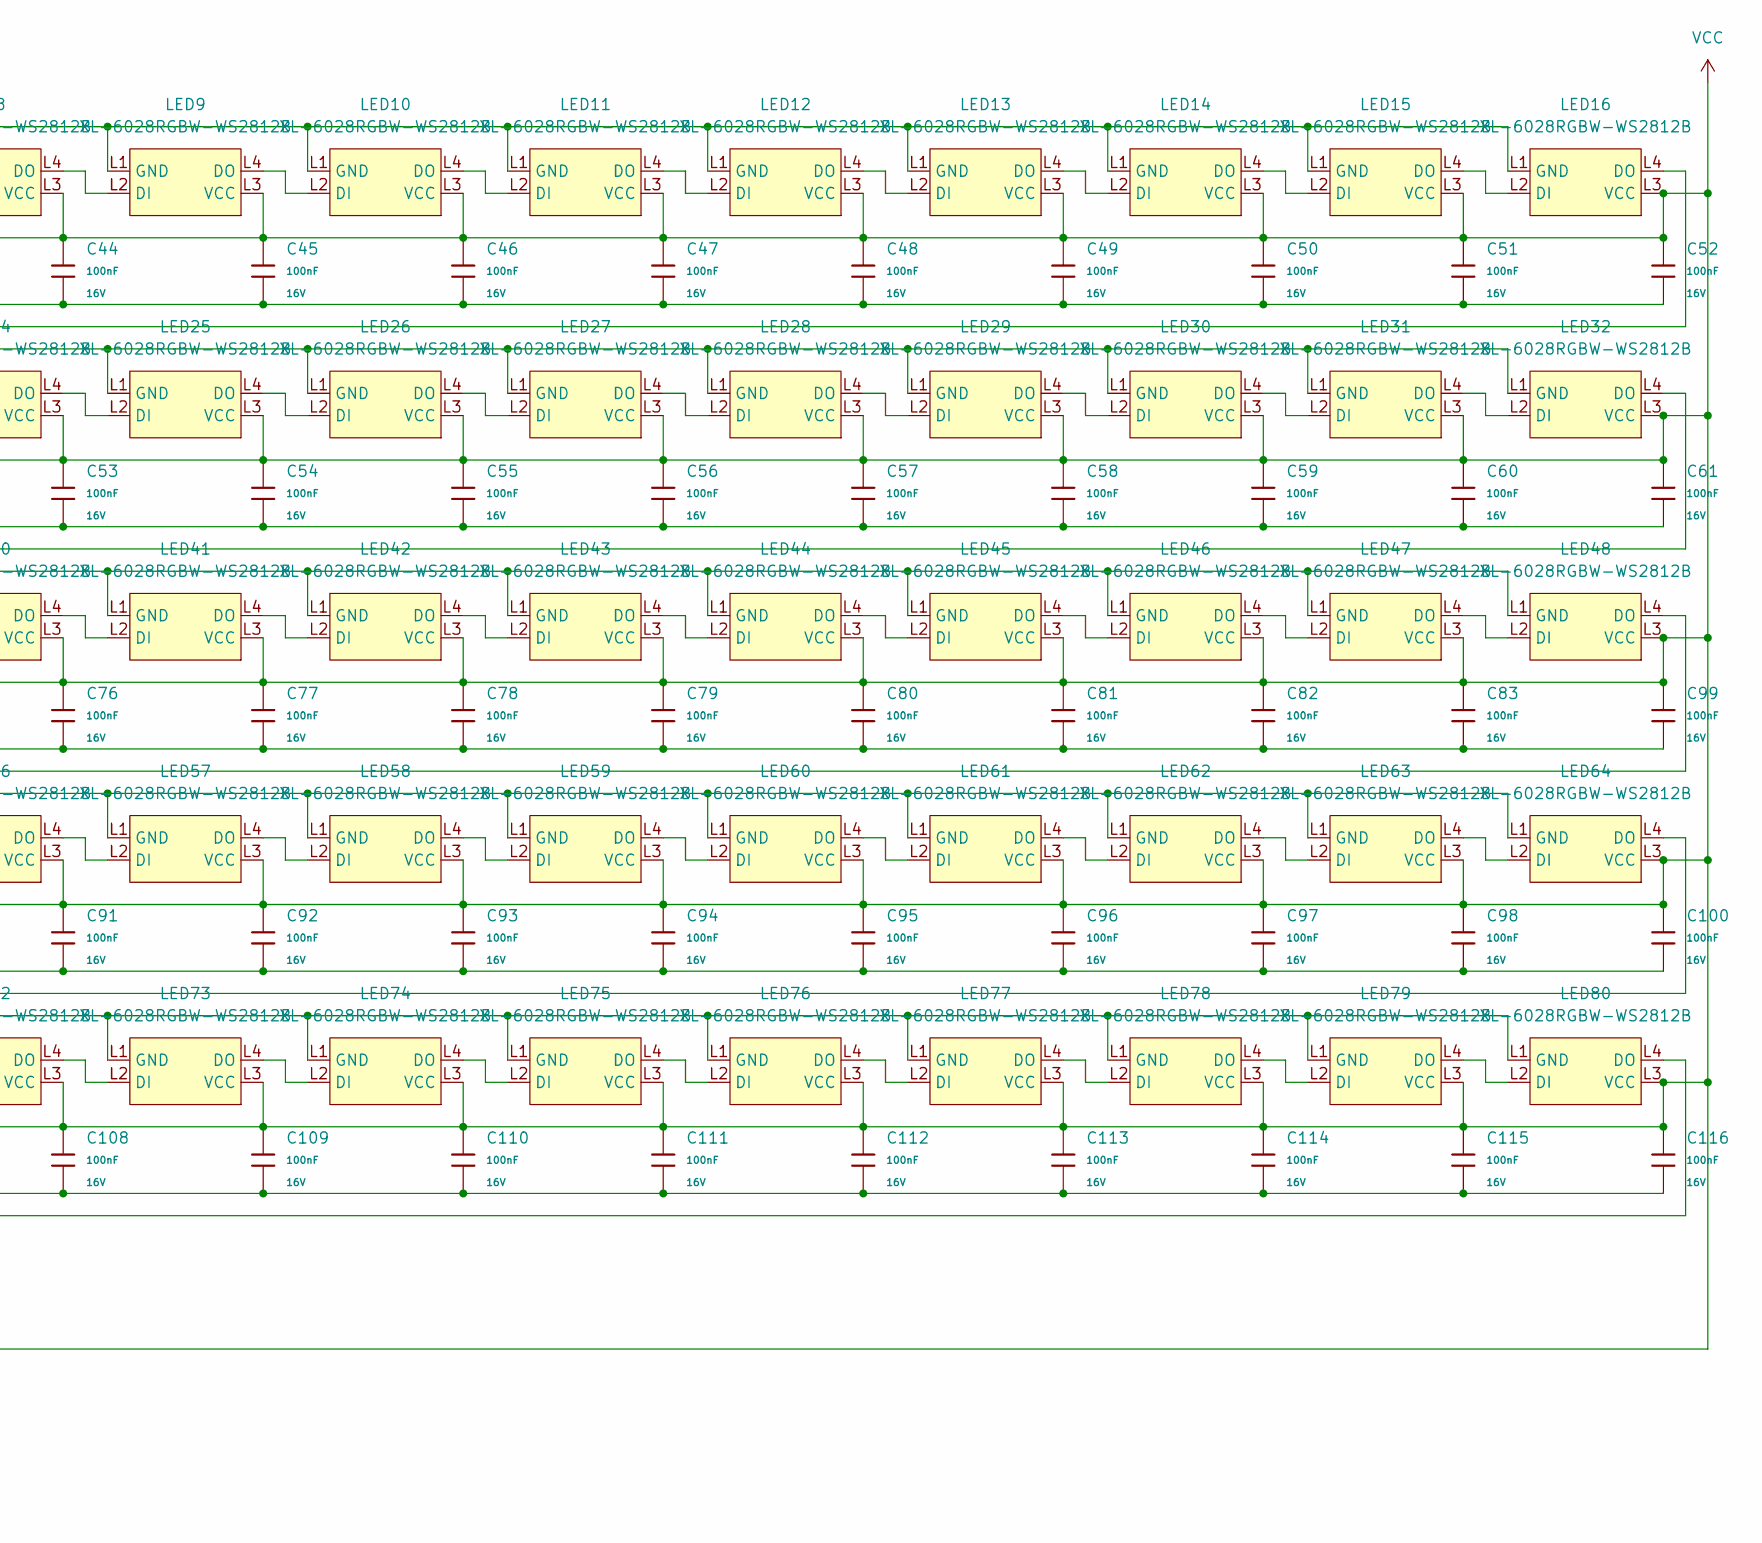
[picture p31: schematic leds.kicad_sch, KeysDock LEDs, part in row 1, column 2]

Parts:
C37, C38, C39, C40, C41, C42, C43, C44, C45, C46, C47, C48, C49, C50, C51, C52, C53, C54, C55, C56, C57, C58, C59, C60, C61, C62, C63, C64, C65, C66, C67, C68, C69, C70, C71, C72, C73, C74, C75, C76, C77, C78, C79, C80, C81, C82, C83, C84, C85, C86, C87, C88, C89, C90, C91, C92, C93, C94, C95, C96, C97, C98, C99, C100, C101, C102, C103, C104, C105, C106, C107, C108, C109, C110, C111, C112, C113, C114, C115, C116, C117, C118: 100nF; C_0402; Voltage Rated 16V; Tolerance ±10%; Part CL05B104KO5NNNC; LCSC C1525
LED1, LED2, LED3, LED4, LED5, LED6, LED7, LED8, LED9, LED10, LED11, LED12, LED13, LED14, LED15, LED16, LED17, LED18, LED19, LED20, LED21, LED22, LED23, LED24, LED25, LED26, LED27, LED28, LED29, LED30, LED31, LED32, LED33, LED34, LED35, LED36, LED37, LED38, LED39, LED40, LED41, LED42, LED43, LED44, LED45, LED46, LED47, LED48, LED49, LED50, LED51, LED52, LED53, LED54, LED55, LED56, LED57, LED58, LED59, LED60, LED61, LED62, LED63, LED64, LED65, LED66, LED67, LED68, LED69, LED70, LED71, LED72, LED73, LED74, LED75, LED76, LED77, LED78, LED79, LED80, LED81, LED82: XL-6028RGBW-WS2812B; LCSC C42163197

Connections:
/leds/TOMO0: LED1.L2 (DI); also elsewhere on the board
GNDD: C37.2, C38.2, C39.2, C40.2, C41.2, C42.2, C43.2, C44.2, C45.2, C46.2, C47.2, C48.2, C49.2, C50.2, C51.2, C52.2, C53.2, C54.2, C55.2, C56.2, C57.2, C58.2, C59.2, C60.2, C61.2, C62.2, C63.2, C64.2, C65.2, C66.2, C67.2, C68.2, C69.2, C70.2, C71.2, C72.2, C73.2, C74.2, C75.2, C76.2, C77.2, C78.2, C79.2, C80.2, C81.2, C82.2, C83.2, C84.2, C85.2, C86.2, C87.2, C88.2, C89.2, C90.2, C91.2, C92.2, C93.2, C94.2, C95.2, C96.2, C97.2, C98.2, C99.2, C100.2, C101.2, C102.2, C103.2, C104.2, C105.2, C106.2, C107.2, C108.2, C109.2, C110.2, C111.2, C112.2, C113.2, C114.2, C115.2, C116.2, C117.2, C118.2, LED1.L1 (GND), LED2.L1 (GND), LED3.L1 (GND), LED4.L1 (GND), LED5.L1 (GND), LED6.L1 (GND), LED7.L1 (GND), LED8.L1 (GND), LED9.L1 (GND), LED10.L1 (GND), LED11.L1 (GND), LED12.L1 (GND), LED13.L1 (GND), LED14.L1 (GND), LED15.L1 (GND), LED16.L1 (GND), LED17.L1 (GND), LED18.L1 (GND), LED19.L1 (GND), LED20.L1 (GND), LED21.L1 (GND), LED22.L1 (GND), LED23.L1 (GND), LED24.L1 (GND), LED25.L1 (GND), LED26.L1 (GND), LED27.L1 (GND), LED28.L1 (GND), LED29.L1 (GND), LED30.L1 (GND), LED31.L1 (GND), LED32.L1 (GND), LED33.L1 (GND), LED34.L1 (GND), LED35.L1 (GND), LED36.L1 (GND), LED37.L1 (GND), LED38.L1 (GND), LED39.L1 (GND), LED40.L1 (GND), LED41.L1 (GND), LED42.L1 (GND), LED43.L1 (GND), LED44.L1 (GND), LED45.L1 (GND), LED46.L1 (GND), LED47.L1 (GND), LED48.L1 (GND), LED49.L1 (GND), LED50.L1 (GND), LED51.L1 (GND), LED52.L1 (GND), LED53.L1 (GND), LED54.L1 (GND), LED55.L1 (GND), LED56.L1 (GND), LED57.L1 (GND), LED58.L1 (GND), LED59.L1 (GND), LED60.L1 (GND), LED61.L1 (GND), LED62.L1 (GND), LED63.L1 (GND), LED64.L1 (GND), LED65.L1 (GND), LED66.L1 (GND), LED67.L1 (GND), LED68.L1 (GND), LED69.L1 (GND), LED70.L1 (GND), LED71.L1 (GND), LED72.L1 (GND), LED73.L1 (GND), LED74.L1 (GND), LED75.L1 (GND), LED76.L1 (GND), LED77.L1 (GND), LED78.L1 (GND), LED79.L1 (GND), LED80.L1 (GND), LED81.L1 (GND), LED82.L1 (GND), LED82.L4 (DO); also elsewhere on the board
unnamed: LED1.L4 (DO), LED2.L2 (DI)
unnamed: LED2.L4 (DO), LED3.L2 (DI)
unnamed: LED3.L4 (DO), LED4.L2 (DI)
unnamed: LED4.L4 (DO), LED5.L2 (DI)
unnamed: LED5.L4 (DO), LED6.L2 (DI)
unnamed: LED6.L4 (DO), LED7.L2 (DI)
unnamed: LED7.L4 (DO), LED8.L2 (DI)
unnamed: LED8.L4 (DO), LED9.L2 (DI)
unnamed: LED9.L4 (DO), LED10.L2 (DI)
unnamed: LED10.L4 (DO), LED11.L2 (DI)
unnamed: LED11.L4 (DO), LED12.L2 (DI)
unnamed: LED12.L4 (DO), LED13.L2 (DI)
unnamed: LED13.L4 (DO), LED14.L2 (DI)
unnamed: LED14.L4 (DO), LED15.L2 (DI)
unnamed: LED15.L4 (DO), LED16.L2 (DI)
unnamed: LED16.L4 (DO), LED17.L2 (DI)
unnamed: LED17.L4 (DO), LED18.L2 (DI)
unnamed: LED18.L4 (DO), LED19.L2 (DI)
unnamed: LED19.L4 (DO), LED20.L2 (DI)
unnamed: LED20.L4 (DO), LED21.L2 (DI)
unnamed: LED21.L4 (DO), LED22.L2 (DI)
unnamed: LED22.L4 (DO), LED23.L2 (DI)
unnamed: LED23.L4 (DO), LED24.L2 (DI)
unnamed: LED24.L4 (DO), LED25.L2 (DI)
unnamed: LED25.L4 (DO), LED26.L2 (DI)
unnamed: LED26.L4 (DO), LED27.L2 (DI)
unnamed: LED27.L4 (DO), LED28.L2 (DI)
unnamed: LED28.L4 (DO), LED29.L2 (DI)
unnamed: LED29.L4 (DO), LED30.L2 (DI)
unnamed: LED30.L4 (DO), LED31.L2 (DI)
unnamed: LED31.L4 (DO), LED32.L2 (DI)
unnamed: LED32.L4 (DO), LED33.L2 (DI)
unnamed: LED33.L4 (DO), LED34.L2 (DI)
unnamed: LED34.L4 (DO), LED35.L2 (DI)
unnamed: LED35.L4 (DO), LED36.L2 (DI)
unnamed: LED36.L4 (DO), LED37.L2 (DI)
unnamed: LED37.L4 (DO), LED38.L2 (DI)
unnamed: LED38.L4 (DO), LED39.L2 (DI)
unnamed: LED39.L4 (DO), LED40.L2 (DI)
unnamed: LED40.L4 (DO), LED41.L2 (DI)
unnamed: LED41.L4 (DO), LED42.L2 (DI)
unnamed: LED42.L4 (DO), LED43.L2 (DI)
unnamed: LED43.L4 (DO), LED44.L2 (DI)
unnamed: LED44.L4 (DO), LED45.L2 (DI)
unnamed: LED45.L4 (DO), LED46.L2 (DI)
unnamed: LED46.L4 (DO), LED47.L2 (DI)
unnamed: LED47.L4 (DO), LED48.L2 (DI)
unnamed: LED48.L4 (DO), LED49.L2 (DI)
unnamed: LED49.L4 (DO), LED50.L2 (DI)
unnamed: LED50.L4 (DO), LED51.L2 (DI)
unnamed: LED51.L4 (DO), LED52.L2 (DI)
unnamed: LED52.L4 (DO), LED53.L2 (DI)
unnamed: LED53.L4 (DO), LED54.L2 (DI)
unnamed: LED54.L4 (DO), LED55.L2 (DI)
unnamed: LED55.L4 (DO), LED56.L2 (DI)
unnamed: LED56.L4 (DO), LED57.L2 (DI)
unnamed: LED57.L4 (DO), LED58.L2 (DI)
unnamed: LED58.L4 (DO), LED59.L2 (DI)
unnamed: LED59.L4 (DO), LED60.L2 (DI)
unnamed: LED60.L4 (DO), LED61.L2 (DI)
unnamed: LED61.L4 (DO), LED62.L2 (DI)
unnamed: LED62.L4 (DO), LED63.L2 (DI)
unnamed: LED63.L4 (DO), LED64.L2 (DI)
unnamed: LED64.L4 (DO), LED65.L2 (DI)
unnamed: LED65.L4 (DO), LED66.L2 (DI)
unnamed: LED66.L4 (DO), LED67.L2 (DI)
unnamed: LED67.L4 (DO), LED68.L2 (DI)
unnamed: LED68.L4 (DO), LED69.L2 (DI)
unnamed: LED69.L4 (DO), LED70.L2 (DI)
unnamed: LED70.L4 (DO), LED71.L2 (DI)
unnamed: LED71.L4 (DO), LED72.L2 (DI)
unnamed: LED72.L4 (DO), LED73.L2 (DI)
unnamed: LED73.L4 (DO), LED74.L2 (DI)
unnamed: LED74.L4 (DO), LED75.L2 (DI)
unnamed: LED75.L4 (DO), LED76.L2 (DI)
unnamed: LED76.L4 (DO), LED77.L2 (DI)
unnamed: LED77.L4 (DO), LED78.L2 (DI)
unnamed: LED78.L4 (DO), LED79.L2 (DI)
unnamed: LED79.L4 (DO), LED80.L2 (DI)
unnamed: LED80.L4 (DO), LED81.L2 (DI)
unnamed: LED81.L4 (DO), LED82.L2 (DI)
VCC: C37.1, C38.1, C39.1, C40.1, C41.1, C42.1, C43.1, C44.1, C45.1, C46.1, C47.1, C48.1, C49.1, C50.1, C51.1, C52.1, C53.1, C54.1, C55.1, C56.1, C57.1, C58.1, C59.1, C60.1, C61.1, C62.1, C63.1, C64.1, C65.1, C66.1, C67.1, C68.1, C69.1, C70.1, C71.1, C72.1, C73.1, C74.1, C75.1, C76.1, C77.1, C78.1, C79.1, C80.1, C81.1, C82.1, C83.1, C84.1, C85.1, C86.1, C87.1, C88.1, C89.1, C90.1, C91.1, C92.1, C93.1, C94.1, C95.1, C96.1, C97.1, C98.1, C99.1, C100.1, C101.1, C102.1, C103.1, C104.1, C105.1, C106.1, C107.1, C108.1, C109.1, C110.1, C111.1, C112.1, C113.1, C114.1, C115.1, C116.1, C117.1, C118.1, LED1.L3 (VCC), LED2.L3 (VCC), LED3.L3 (VCC), LED4.L3 (VCC), LED5.L3 (VCC), LED6.L3 (VCC), LED7.L3 (VCC), LED8.L3 (VCC), LED9.L3 (VCC), LED10.L3 (VCC), LED11.L3 (VCC), LED12.L3 (VCC), LED13.L3 (VCC), LED14.L3 (VCC), LED15.L3 (VCC), LED16.L3 (VCC), LED17.L3 (VCC), LED18.L3 (VCC), LED19.L3 (VCC), LED20.L3 (VCC), LED21.L3 (VCC), LED22.L3 (VCC), LED23.L3 (VCC), LED24.L3 (VCC), LED25.L3 (VCC), LED26.L3 (VCC), LED27.L3 (VCC), LED28.L3 (VCC), LED29.L3 (VCC), LED30.L3 (VCC), LED31.L3 (VCC), LED32.L3 (VCC), LED33.L3 (VCC), LED34.L3 (VCC), LED35.L3 (VCC), LED36.L3 (VCC), LED37.L3 (VCC), LED38.L3 (VCC), LED39.L3 (VCC), LED40.L3 (VCC), LED41.L3 (VCC), LED42.L3 (VCC), LED43.L3 (VCC), LED44.L3 (VCC), LED45.L3 (VCC), LED46.L3 (VCC), LED47.L3 (VCC), LED48.L3 (VCC), LED49.L3 (VCC), LED50.L3 (VCC), LED51.L3 (VCC), LED52.L3 (VCC), LED53.L3 (VCC), LED54.L3 (VCC), LED55.L3 (VCC), LED56.L3 (VCC), LED57.L3 (VCC), LED58.L3 (VCC), LED59.L3 (VCC), LED60.L3 (VCC), LED61.L3 (VCC), LED62.L3 (VCC), LED63.L3 (VCC), LED64.L3 (VCC), LED65.L3 (VCC), LED66.L3 (VCC), LED67.L3 (VCC), LED68.L3 (VCC), LED69.L3 (VCC), LED70.L3 (VCC), LED71.L3 (VCC), LED72.L3 (VCC), LED73.L3 (VCC), LED74.L3 (VCC), LED75.L3 (VCC), LED76.L3 (VCC), LED77.L3 (VCC), LED78.L3 (VCC), LED79.L3 (VCC), LED80.L3 (VCC), LED81.L3 (VCC), LED82.L3 (VCC); also elsewhere on the board

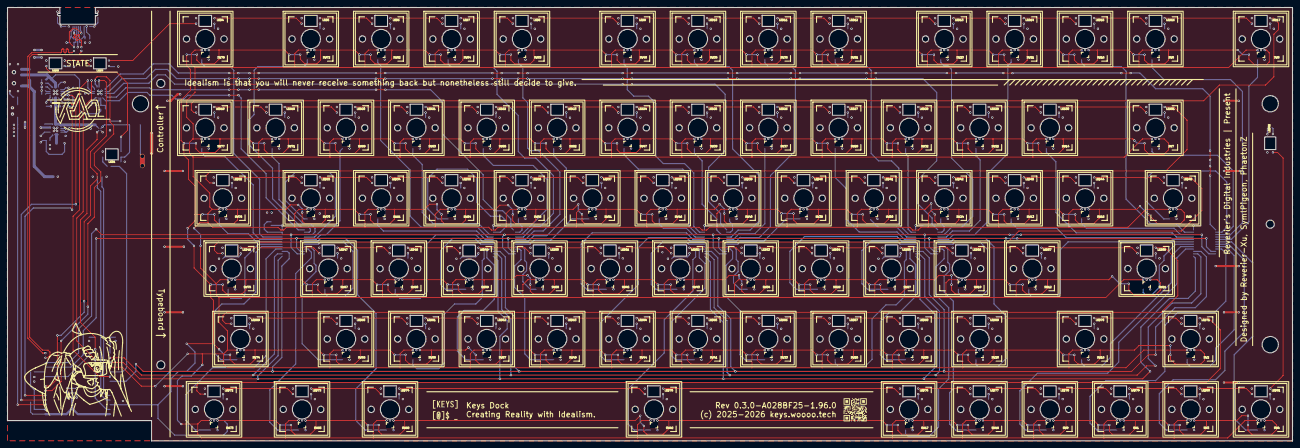
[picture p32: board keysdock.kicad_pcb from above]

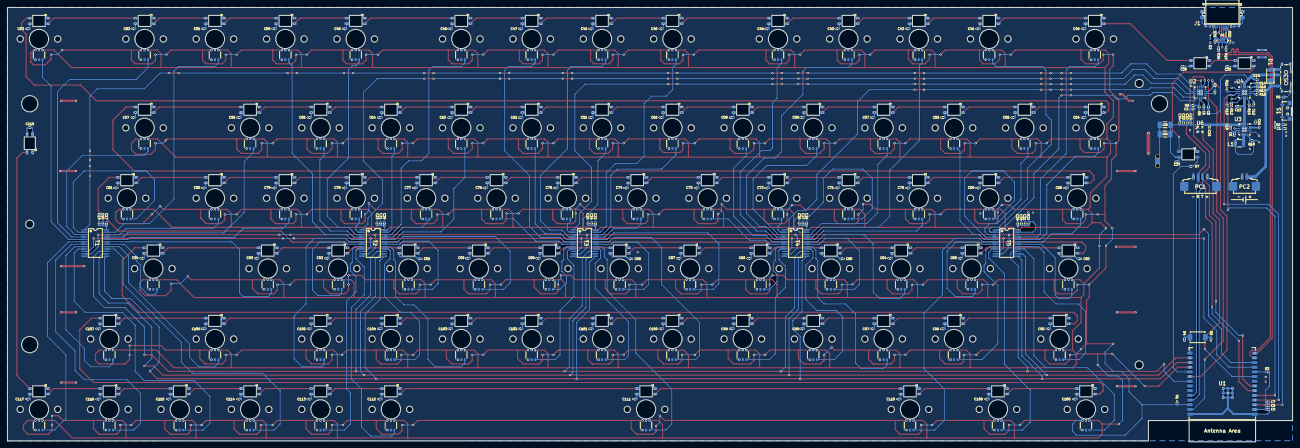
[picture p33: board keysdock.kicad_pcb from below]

Board: 4 copper layers, 347.8 x 117.3 mm, 322 parts (161 on the bottom side), 214 nets.

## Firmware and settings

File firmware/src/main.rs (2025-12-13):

#![no_std]
#![no_main]
#![deny(
  clippy::mem_forget,
  reason = "mem::forget is generally not safe to do with esp_hal types, especially those holding buffers for the duration of a data transfer."
)]
#![deny(clippy::large_stack_frames)]

use esp_backtrace as _;

// This creates a default app-descriptor required by the esp-idf bootloader.
// For more information see: <https://docs.espressif.com/projects/esp-idf/en/stable/esp32/api-reference/system/app_image_format.html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>
esp_bootloader_esp_idf::esp_app_desc!();

#[esp_rtos::main]
async fn main(spawner: embassy_executor::Spawner) {
  rtt_target::rtt_init_defmt!();

  let config = esp_hal::Config::default().with_cpu_clock(esp_hal::clock::CpuClock::max());
  let peripherals = esp_hal::init(config);

  esp_alloc::heap_allocator!(#[esp_hal::ram(reclaimed)] size: 65536);
  // COEX needs more RAM
  esp_alloc::heap_allocator!(size: 64 * 1024);

  let timg0 = esp_hal::timer::timg::TimerGroup::new(peripherals.TIMG0);
  let sw_interrupt =
    esp_hal::interrupt::software::SoftwareInterruptControl::new(peripherals.SW_INTERRUPT);
  esp_rtos::start(timg0.timer0, sw_interrupt.software_interrupt0);

  let _ = spawner;

  loop {
    embassy_time::Timer::after(embassy_time::Duration::from_secs(1)).await;

    defmt::info!("Hello, world!");
  }
}

#[panic_handler]
fn panic(_: &core::panic::PanicInfo) -> ! {
  loop {}
}

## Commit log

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2025-10-08 :sparkles: try background suit
    [background.stl]
2025-10-09 :construction: add keyboard layout
    [backsuit.FCStd, backsuit.stl]
2025-10-10 :sparkles: update plate and backsuit
    [backsuit.FCStd, backsuit.stl, plate.FCStd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]
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2025-10-11 :construction: may finish main design
    [backsuit.FCStd, design.FCStd, enclosure.stl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]
2025-10-12 :sparkles: add side cover
    [design.FCStd, enclosure.stl, plate.dxf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]
2025-10-12 :sparkles: add step files
    [design.FCStd, enclosure.step, plate.step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]
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2025-10-15 :sparkles: main board finished
    [backcover.dxf, sidecover-rx.dxf, sidecover.dxf]
2025-10-15 :truck: move directory archs
    [backcover.dxf, enclosure.step, enclosure.stl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]
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2025-10-15 :art: add logo to sidecover
    [sidecover.dxf]
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2025-10-26 :construction: new suite kits design
    [full.FCStd, plate-ext.dxf, plate-main.dxf]
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2025-10-28 :truck: change to kicad
    [C_0402.step, C_0603.step, KS-33D-FB.step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]
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2025-10-29 :construction: draw some components
    [full.FCStd, keys-group.kicad_sch, plate-main-hole.dxf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]
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2025-10-31 :fire: remove external adc, use internal adc io pins
    [POGOPIN-8P-HS.FCStd, controller.kicad_sch, full.FCStd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]
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2025-11-03 :construction: controller pcb shape
    [controller.kicad_pcb, full.FCStd]
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2025-11-04 :sparkles: add some components
    [SOT-223-4P_L6.5-W3.5-H1.6-LS7.0-P2.30.step, controller.kicad_sch]
2025-11-05 ADD TESTPAD
    ADD TESTPAD
    [TESTPAD.kicad_pcb, TESTPAD.kicad_sch]
2025-11-08 :recycle: refactor symbol lib
    [L_0805.step, TESTPAD.kicad_pcb, TESTPAD.kicad_sch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]
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2025-11-14 :sparkles: finish 2-piece pcb design
    [keys-group.kicad_sch]
2025-11-14 :fire: rework
    [keys-group.kicad_sch]
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2025-11-16 :construction: add 4 layer
    [controller.kicad_sch]
2025-11-16 :sparkles: rounded 3v3 route corner
    [controller.kicad_sch, typeboard.kicad_pcb]
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2025-11-17 👆UPDATE SOME CONTROLLER LINE
    [controller.kicad_pcb]
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2025-11-25 :sparkles: add ijichi nijika drawings
    [controller.kicad_pcb]
2025-11-28 :construction: add controller switchs
    [SMD_4P-L3.5-W2.8-BR-1.step, SW-SMD_SSSS811101.step, controller.kicad_pcb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]
2025-11-30 :construction: run DRC on controller board
    [controller.kicad_pcb, controller.kicad_sch, full.FCStd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]
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2025-12-06 :memo: reviewed by hankz
    [controller.kicad_pcb, typeboard.kicad_pcb, typeboard.kicad_sch]
2025-12-09 :construction: add capacitors to ADC pin
    [controller.kicad_pcb, controller.kicad_sch, typeboard.kicad_pcb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]
2025-12-13 :construction: add external board init
    [external.kicad_sch]
2025-12-14 :sparkles: external board design
    [controller.kicad_pcb, controller.kicad_sch, external.kicad_pcb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]
2025-12-19 :sparkles: add CH334P & CH343P to components library
    [CH334P.step, CH343P.step, controller.kicad_pcb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]
2025-12-29 :sparkles: add battery management (#1)
    [controller.kicad_sch]
2025-12-29 :sparkles: refine capacitors and crystals, finish charge chip
    [Crystal_SMD-3225-4P.step, controller.kicad_sch]
2025-12-29 :fire: reduce battery size
    [full.FCStd]
2025-12-31 :sparkles: finish pcb layout of controller
    [AXK5F16347YG.step, AXK5F20347YG.step, AXK6F16347YG.step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]
2026-01-01 :fire: remove CH-series chips and use legacy UART
    [HC-1.25-2PWT.step, HC-1.25-4PWT.step, controller.kicad_pcb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]
2026-01-02 :sparkles: use side reset button
    [HC-1.25-2PWT.step, HC-1.25-4PWT.step, TS24CA.step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]
2026-01-02 :sparkles: finish all hardware designs except external
    [EC12E1240301.step, connector.kicad_pcb, connector.step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]
2026-01-02 :sparkles: finish all hardware designs
    [controller.kicad_pcb, controller.kicad_sch, external.kicad_pcb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]
2026-01-02 :sparkles: add step file for pcb
    [pcb-connector.step, pcb-external.step]
2026-01-02 :sparkles: add silk tips for external board
    [external.kicad_pcb, full.FCStd, typeboard.kicad_pcb]
2026-01-03 :sparkles: add sheet template
    [connector.kicad_sch, controller.kicad_sch, external.kicad_sch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]
2026-01-03 :sparkles: assembly all the part!
    [FPC-SMD_AFA01-S08FCA-00.step, HC-TYPE-C-16P-CB1.6.step, connector.kicad_pcb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]
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2026-01-06 :art: improve LED positions
    [LED-SMD_XL-3512RGBW.step, backcover.dxf, connector.kicad_pcb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]
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2026-01-08 :sparkles: add bom table
    [connector.kicad_pcb, connector.kicad_sch, controller.kicad_pcb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]
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2026-01-22 :bug: fix switch hole
    [controller.kicad_pcb, testpad.kicad_pcb]
2026-02-12 :construction: panelize all boards
    [controller.kicad_pcb, external.kicad_pcb, external.kicad_sch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]
2026-03-22 :fire: remove panelized one
    [panelized.kicad_sch]
2026-03-22 :arrow_up: update to KiCAD 10.0
    [connector.kicad_pcb, connector.kicad_sch, controller.kicad_pcb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]
2026-03-23 :bug: improve hardware design
    [connector.kicad_pcb, controller.kicad_pcb, controller.kicad_sch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]
2026-03-23 :sparkles: esd protection for type-c
    [TPD1E10B06DPYR.step, TPD4E05U06DQAR.step, controller.kicad_pcb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]
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2026-03-24 :zap: improve led power supply
    [TPS22910AYZVR.step, controller.kicad_pcb, controller.kicad_sch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]
2026-03-25 :bug: fix L1
    [controller.kicad_pcb, controller.kicad_sch]
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2026-06-06 :bug: connect plane gaps for USB_D+/-
    [keysdock.kicad_pcb]
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2026-07-12 :construction: fix sw positions
    [bom.csv, designators.csv, keysdock.kicad_sch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]
2026-08-08 :sparkles: add ESP32-S31-WROOM-3 library assets
    Add a datasheet-verified symbol, land pattern, and official 3D model so
    the next board revision can migrate from ESP32-C6 without relying on
    unverified CAD data.
    [ESP32-S31-WROOM-3.step]
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
